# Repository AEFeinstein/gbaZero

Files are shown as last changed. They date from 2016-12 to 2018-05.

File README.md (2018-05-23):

View this project on [CADLAB.io](https://cadlab.io/project/1072). 

# gbaZero

One day I decided to buy a broken Gameboy Advance, gut it, and replace the innards with a Raspberry Pi powered board. This style of project has been attempted before in custom plastic (see [Game Grrl](https://learn.adafruit.com/game-grrl) and its derivitaves) and Nintendo plastic (see [Ryzee119's project](https://github.com/Ryzee119/GBA_Emulator-by-Ryzee119-) and [Game Pie Advance](http://gamepieadvance.com/)). Here's a little build log for my version of this project.

## Design

The design process was mostly me sitting at my desk doing research and CAD work in Inkscape and EAGLE.

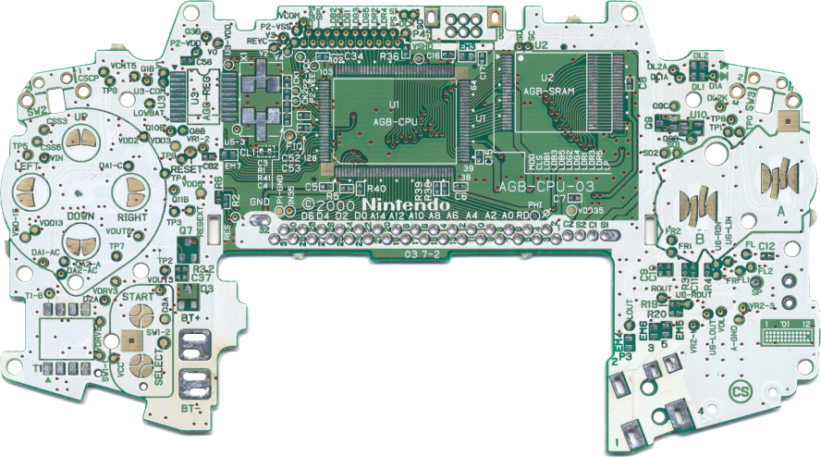
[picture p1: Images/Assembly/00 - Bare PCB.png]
00 - Bare PCB.png

To get the right PCB shape, I desoldered all the parts from a sacrificial PCB and took a 600dpi scan of it.

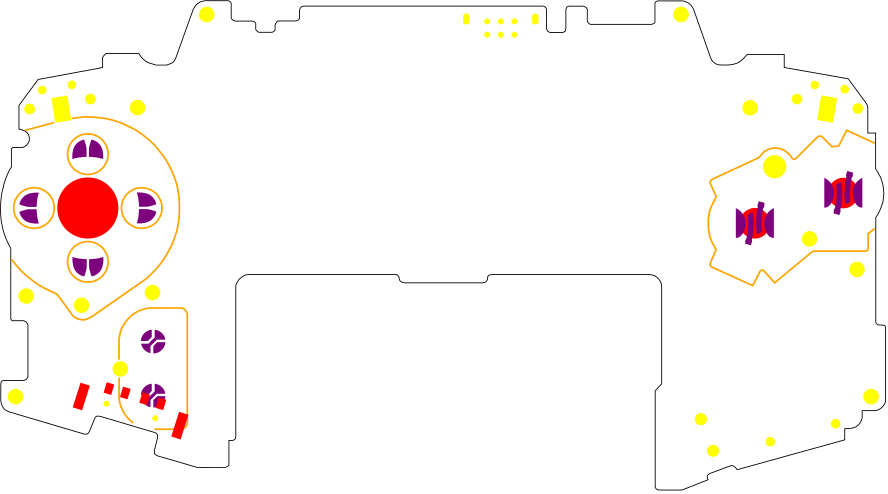
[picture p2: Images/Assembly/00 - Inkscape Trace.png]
00 - Inkscape Trace.png

That scan was then traced in Inkscape, and the resulting SVG was imported into EAGLE using [cmonr's svg2poly ULP](https://github.com/cmonr/Eagle-ULPs).

I wanted the wacky button footprints to be just like Nintendo's. I had a scan of the footprints open in an image viewer, overlaid an EAGLE window made transparent by [Peek Through](http://www.lukepaynesoftware.com/projects/peek-through/), and traced out the shape using the polygon tool. It's kind of like a high tech lightbox.

Ultimately I threw my work on the board shape and drilled holes out the window in favor of the shape from Ryzee119's project. I was almost guaranteed to mess something, and their's was already tested to be the right fit, so that seemed safer. I was also unaware of Ryzee119's project when I started all the scanning and tracing. I did keep the Nintendo-esque button footprints.

## Assembling the Hardware

### Power Circuitry

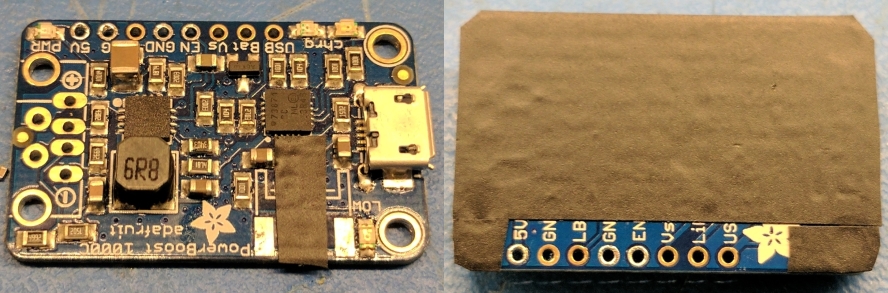
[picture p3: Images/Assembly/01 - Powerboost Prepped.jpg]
01 - Powerboost Prepped.jpg

It turns out using someone else's work is often easier than doing it yourself. In this case, I used a [PowerBoost 1000C](https://www.adafruit.com/products/2465) to manage charging the battery and supplying power for this board. It's a capable little board, so all I had to do was desolder the JST battery connector to trim the height and cover the backside with electrical tape because it will sit flush on the main board.

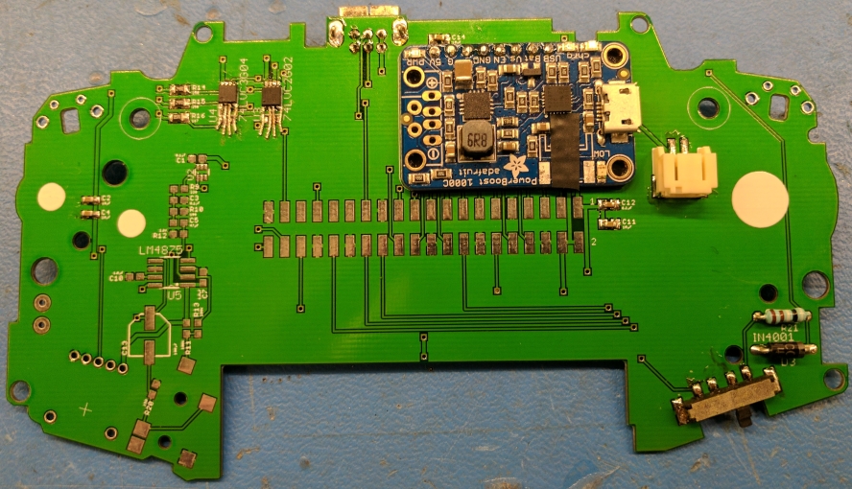
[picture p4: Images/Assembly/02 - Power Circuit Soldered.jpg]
02 - Power Circuit Soldered.jpg

Here's the power circuit all soldered up. I'm using a common anode tricolor LED and some NOR gates and inverters to display the GBA's state (powered on, charging, or low battery). The logic ICs are in the top left and the LED is on the other side of the board.

The switch in the bottom right was salvaged from a broken GBA. I couldn't find where to source a replacement for the life of me. The resistor and diode in the bottom right are a way to have the Raspberry Pi power off cleanly. Sure, one could just cut power to the Pi, but that puts the SD card at risk for corruption. The Enable pin on the PowerBoost is tied to both the switch and a GPIO (through a diode, so the GPIO doesn't get backpowered), so when the Pi boots it holds the PowerBoost on, even if the switch is turned off. Flicking the switch off does trigger a shutdown script, which shuts down cleanly and disables the PowerBoost at the end.

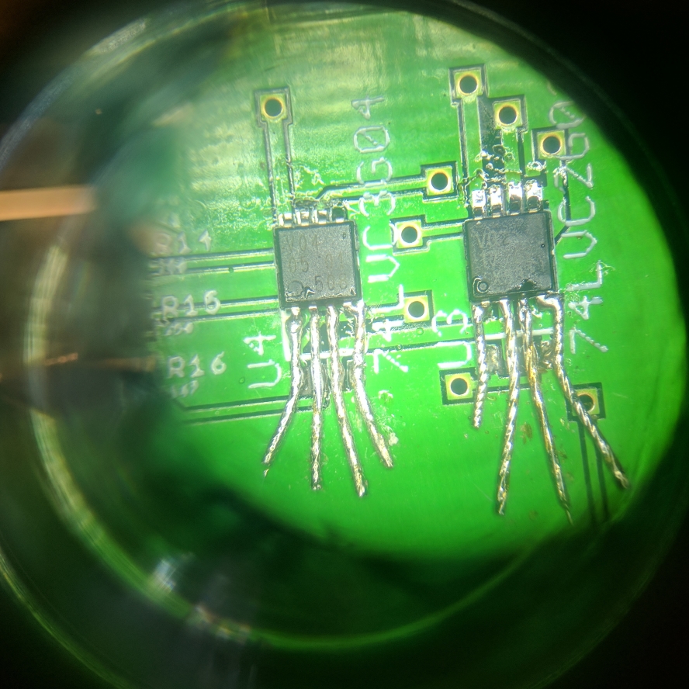
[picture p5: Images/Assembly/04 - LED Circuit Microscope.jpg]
04 - LED Circuit Microscope.jpg

Uhoh, notice those ugly wires coming off the logic ICs in the previous image? Turns out I either used the wrong footprint in EAGLE or ordered the wrong package part from Digi-Key. Either way, it needed some bridging. I realized I could take pictures with my phone through the stereo microscope in the lab, so I did. I trimmed the wires after this shot, and cleaned up the extra flux too.

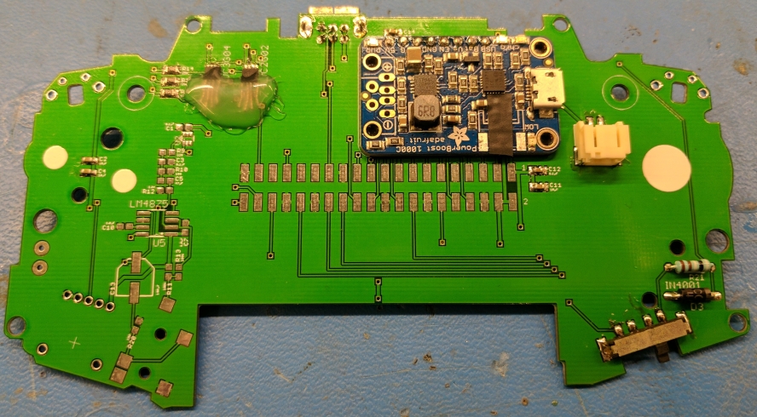
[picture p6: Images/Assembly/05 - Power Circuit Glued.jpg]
05 - Power Circuit Glued.jpg

There's nothing like a little hot glue to keep everything in place!

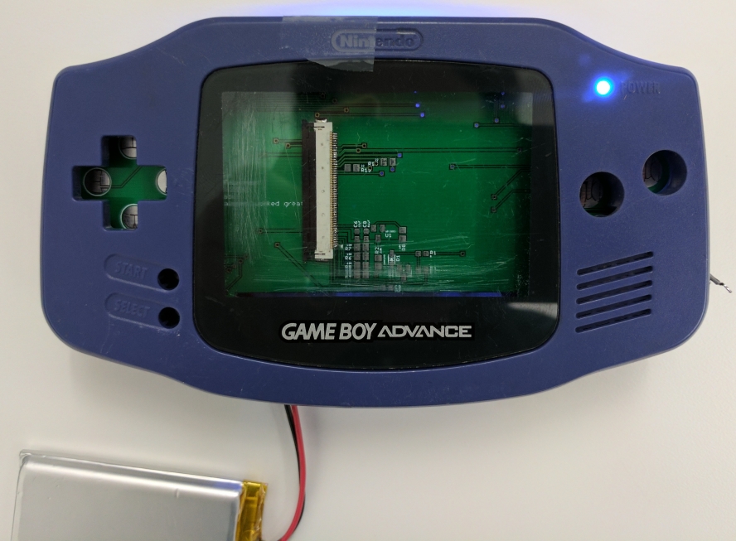
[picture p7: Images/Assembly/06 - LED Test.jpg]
06 - LED Test.jpg

Ta-da! The LED works and is in the right place for the light pipe. It may be a little too bright, but that's nothing a larger current limiting resistor can't fix. The LED is blue when the unit is powered on, green when it is charging, and red when the battery is low. The one wrinkle is that the LED is off when the unit is off, but charging. The original design assumed a common cathode LED instead of a common anode LED, which is what I ended up finding on Digi-Key. Rather than redo the logic, I just threw an inverter on at the end. Unfortunately the inverter was powered by the regulated voltage, so it doesn't invert unless the unit is on. Had the LED been common cathode, it would have been driven by the 5V USB charging voltage. Ah well.

Also of note, the board uses the original Link Cable connector and a custom cable for charging. The Raspberry Pi's RX and TX pins are also exposed on the Link Cable connector, so with an FTDI cable one can log into a terminal and fiddle around with the system. This ended up being way more convenient than SSHing into the system over wifi.

### Display Circuitry

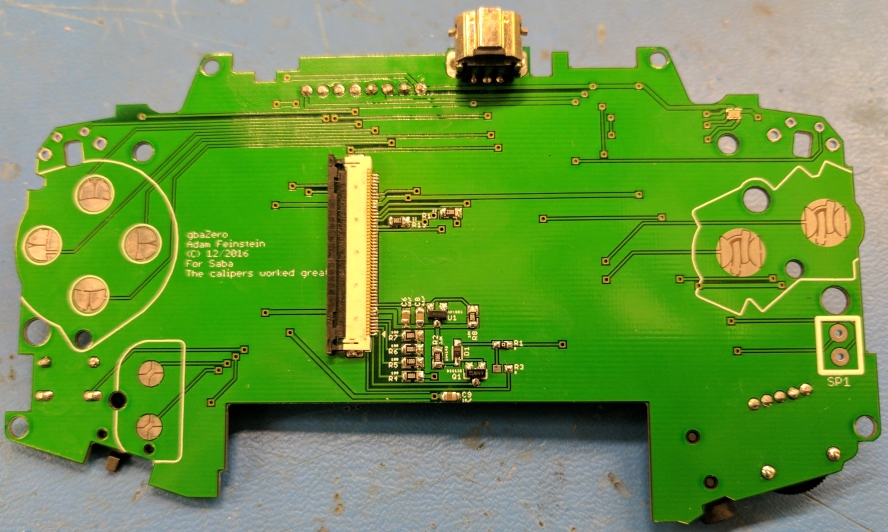
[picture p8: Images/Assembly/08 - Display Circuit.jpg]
08 - Display Circuit.jpg

Remember that part about using someone else's work? I'll call it standing on the shoulders of giants. Turns out Adafruit sells a [2.8" Raspberry Pi display](https://www.adafruit.com/products/2423) which fits pretty perfectly in a GBA. I took the [circuitry from their board](https://github.com/adafruit/Adafruit-PiTFT-Plus-2.8-PCB) and transposed it onto mine. Should work perfectly, right? Yeah, we'll get to that.

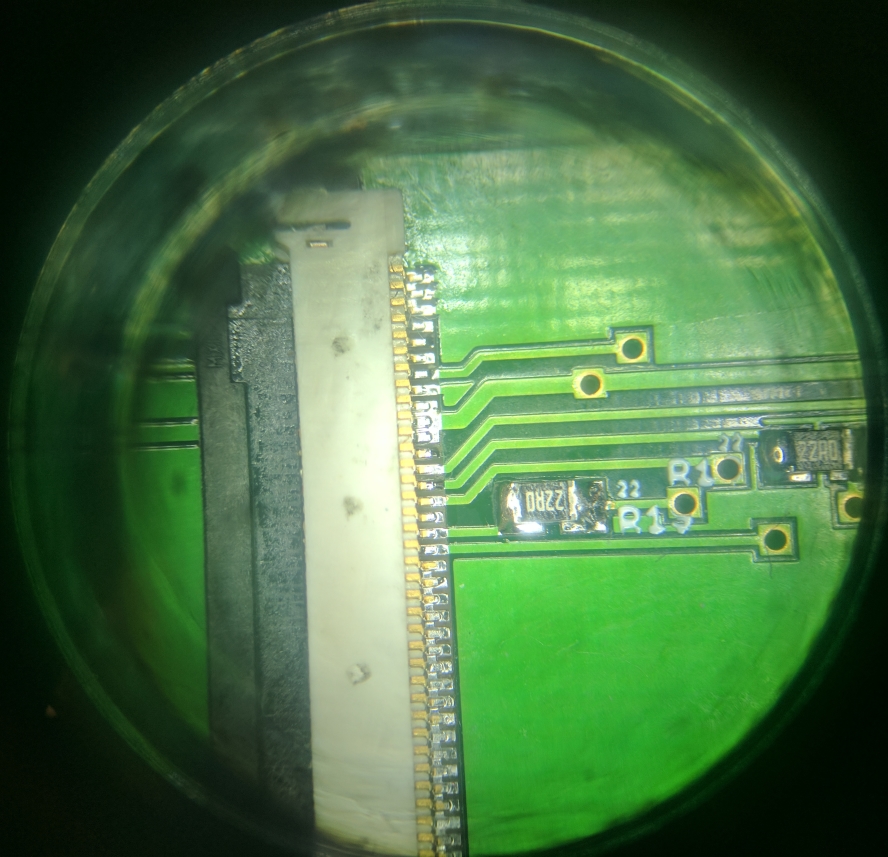
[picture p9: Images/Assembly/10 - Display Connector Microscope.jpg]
10 - Display Connector Microscope.jpg

Here's a gratuitious microscope shot. The display connector had 0.5mm pitch pins, which is the smallest thing I've soldered. Solder braid makes everything look super clean (and not bridged).

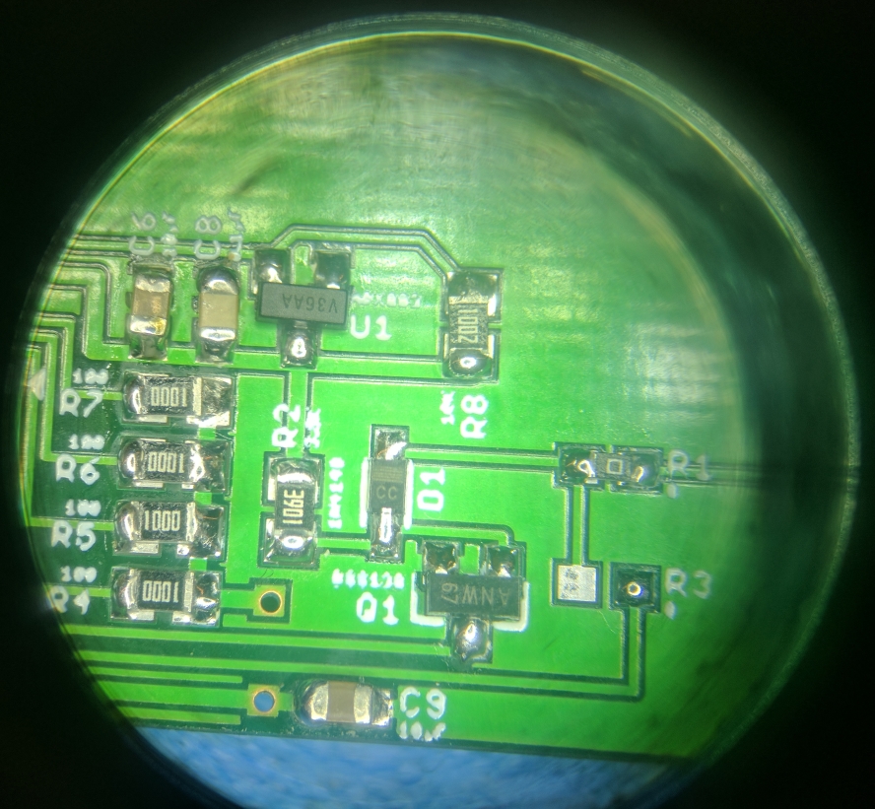
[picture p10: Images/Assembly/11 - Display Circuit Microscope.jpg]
11 - Display Circuit Microscope.jpg

Oh yeah, I was going wild with that microscope. There's actually a problem in this picture. I'll get to that shortly.

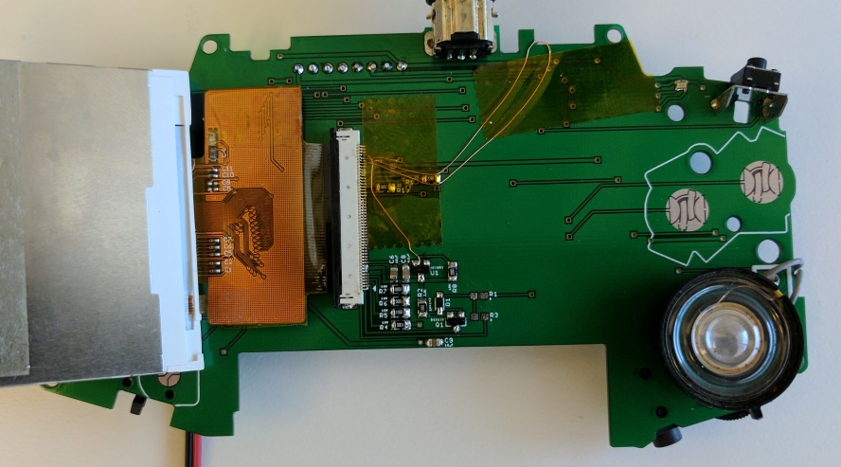
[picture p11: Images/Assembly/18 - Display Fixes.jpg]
18 - Display Fixes.jpg

Transposing a circuit only works if you do it correctly, which I did not. I crossed the I2C lines which send touchscreen data to the Raspberry Pi, so I had to cut those traces with a knife and reroute them with magnet wire. Those are the two wires going off the edge of the board. That didn't matter so much as I wasn't using the touchscreen anyway, but I like to be proper. The bigger issue is that I completely missed a trace that had been connected with a 0 ohm resistor on Adafruit's board. That was fixed with the third magnet wire running from the display connector to U1. I opted for kapton tape instead of hot glue to hold these fixes in place.

There was another issue with the display circuitry that prevented an image from being displayed, hinted at before. U1 is an APX803 voltage supervisor on a 3.3V line. However, I bought an APX803 which had a 4.63V threshold. D'oh. The Adafruit schematic didn't note the treshold level, and I must not have been paying much attention while filling my shopping cart. In lieu of ordering another supervisor, I stole the one from the Adafruit board and dropped it on mine.

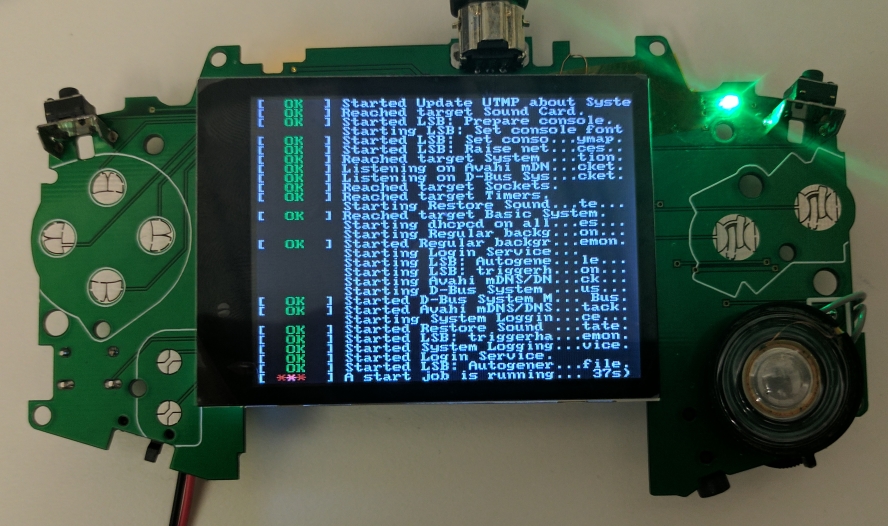
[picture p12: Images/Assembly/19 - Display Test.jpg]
19 - Display Test.jpg

Ta-da! With a few magnet wire fixes and a new supervisor, there's an image! This testing and debugging was done after all the parts were soldered, so these images aren't quite in chronological order. It would be hard to display anything without the Raspberry Pi.

### Audio Circuitry

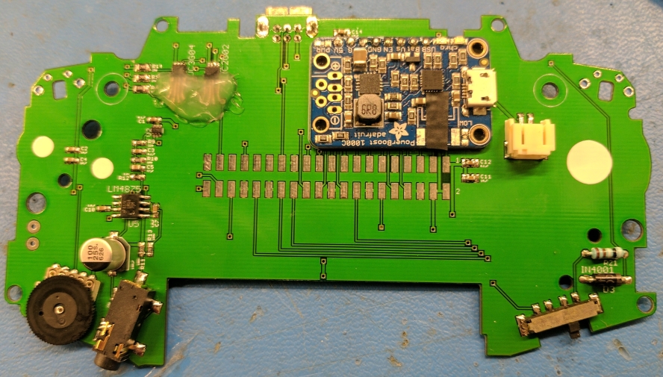
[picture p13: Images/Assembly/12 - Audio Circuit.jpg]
12 - Audio Circuit.jpg

While most Raspberry Pis have audio output, the Zero does not. It's the cost to pay for a tiny $5 board. Luckily, it can still output a PWM audio signal. A little RC filtering and amplifying later, and it should be good to go. The headphone jack and volume potentiometer were new parts. A minor annoyance, GND and 5V are swapped on the volume potentiometer, so rotating it towards max volume (according to the plastic shell) makes it quieter. 

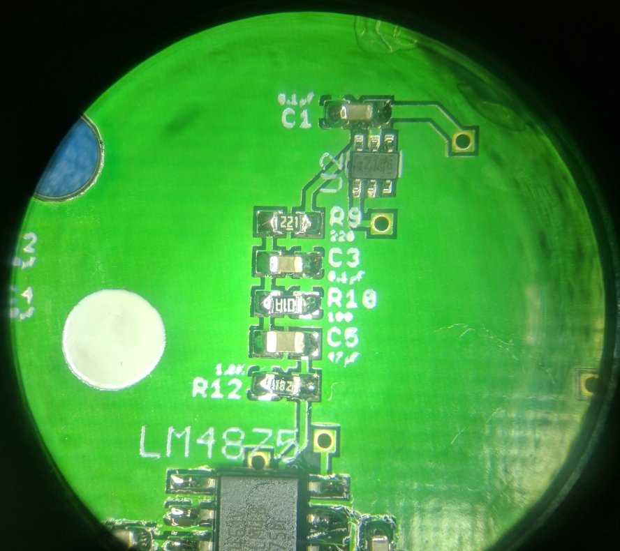
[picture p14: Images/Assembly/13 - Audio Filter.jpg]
13 - Audio Filter.jpg

Here's a microscope shot of the buffer and five passives that make up the filter. The design was taken from the Raspberry Pi 3 schematic. Once again, there's a problem in here. More on that shortly.

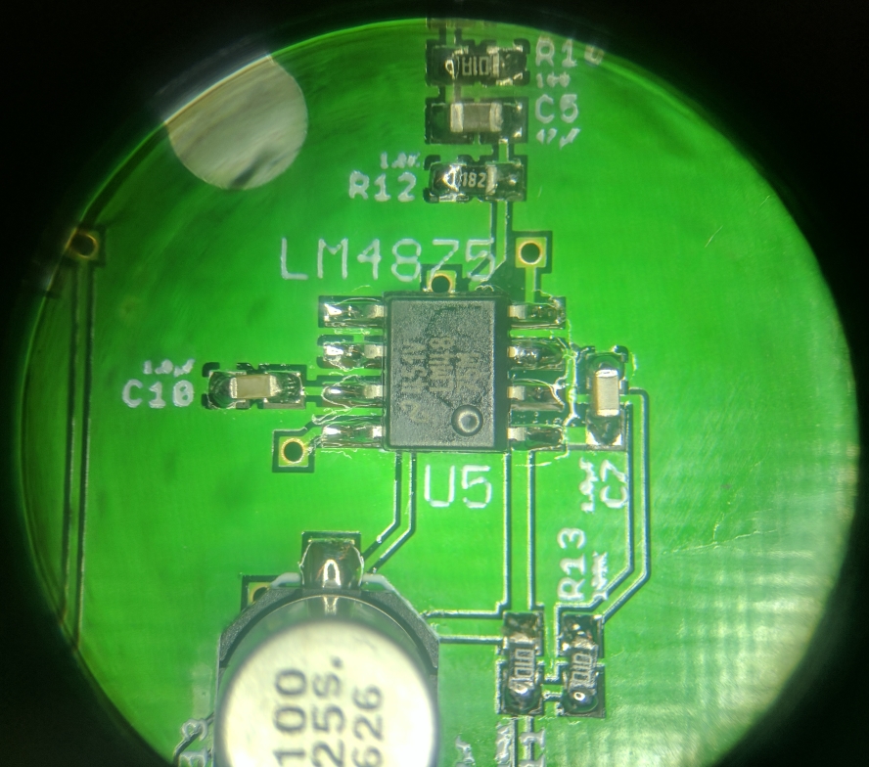
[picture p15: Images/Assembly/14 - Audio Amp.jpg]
14 - Audio Amp.jpg

The amplifier is an LM4875. That amp only does mono sound, but it can automatically switch between a speaker and a headphone jack. An earlier design had a separate analog switch IC which could handle stereo output, but was way more cumbersome. The GBA only has one speaker anyway (though headphones have two).

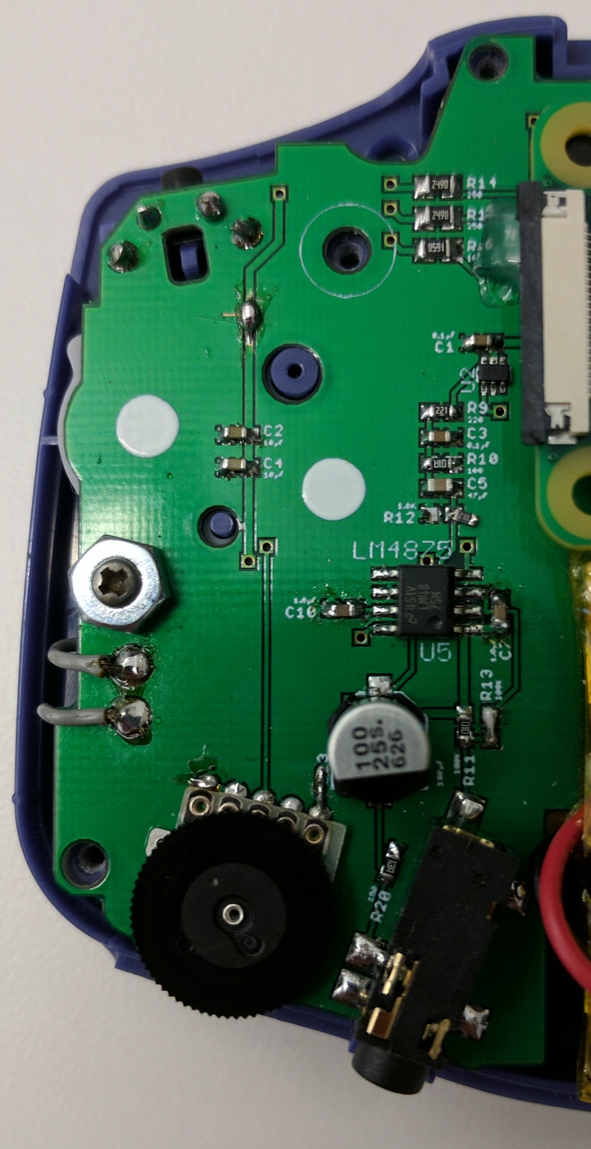
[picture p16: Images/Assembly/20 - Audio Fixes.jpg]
20 - Audio Fixes.jpg

So about that problem, when I went to test the audio, the speaker got hot. As a colleague said "you can't hear DC," and indeed there was an unexpected DC voltage across the speaker. The [Raspberry Pi 3 schematic](https://www.raspberrypi.org/documentation/hardware/raspberrypi/schematics/RPI-3B-V1_2-SCHEMATIC-REDUCED.pdf) I copied the audio circuitry from had a pulldown resistor right before the audio jack. This is great for headphones or speakers or what-have-you, but terrible for amplifier input. In fact, the [LM4875 datasheet](http://www.ti.com/lit/ds/symlink/lm4875.pdf) says to put a 0.22uF capacitor in line with the input signal to get rid of incoming DC voltage, which I did not do. All that had to change was to remove the last pulldown resistor before the amplifier and let the last capacitor filter out all the DC voltage. You can see R12 hanging off into nowhere, just so I wouldn't lose it.

This took me forever to figure out, and in fact the solution was proposed by a colleague who earned his name in the silkscreen for version two. Some failed debugging attempts were powering the audio circuitry with 3.3V instead of 5V (the cut and solder blob in the top left), replacing R13 with a wire, dis/reconnecting the volume potentiometer, and changing bypass capacitor values (C7 is two stacked capacitors in the picture above). Gross.

### Raspberry Pi Zero

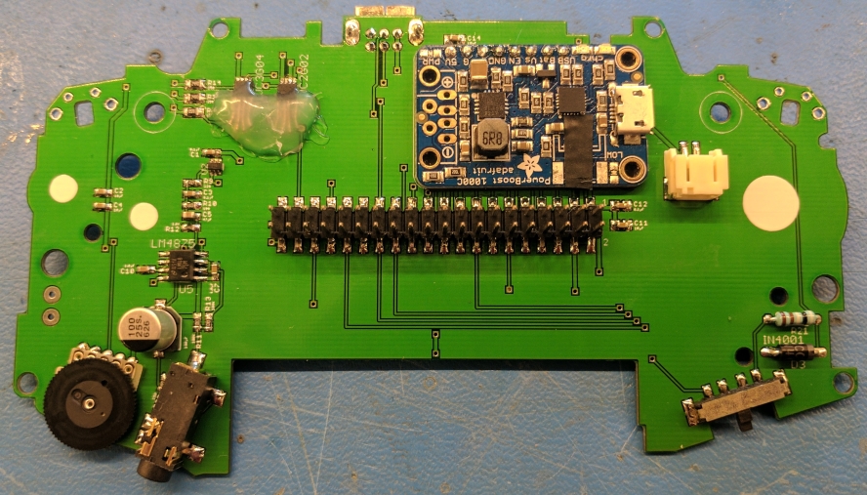
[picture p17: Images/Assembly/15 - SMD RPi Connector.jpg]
15 - SMD RPi Connector.jpg

Soldering on the Raspberry Pi proved to be the one part of this project that went as expected. First I soldered on a 40 pin SMD connector.

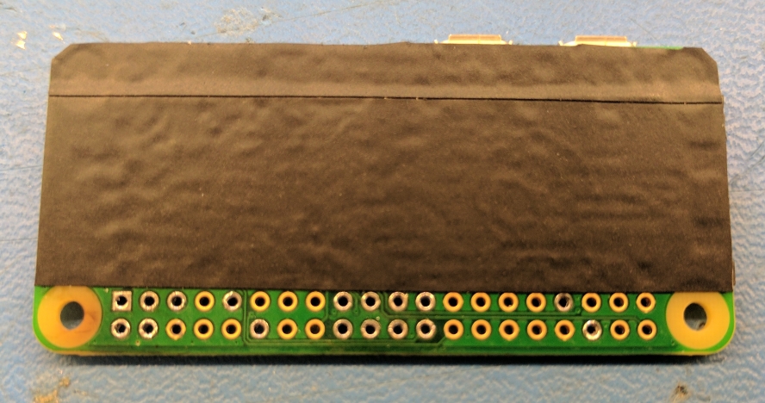
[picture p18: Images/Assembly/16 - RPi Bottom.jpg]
16 - RPi Bottom.jpg

Then I taped the bottom of the Raspberry Pi, since it would cantilever over the PowerBoost.

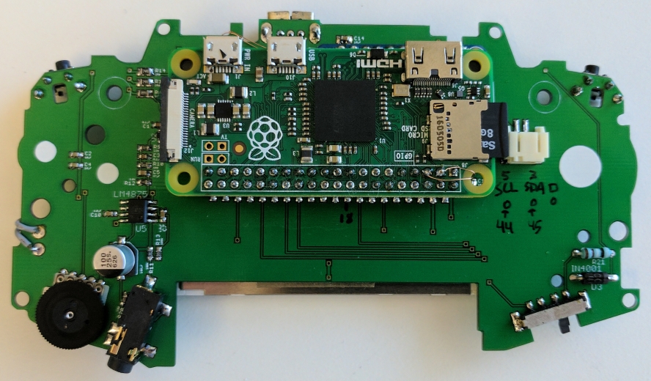
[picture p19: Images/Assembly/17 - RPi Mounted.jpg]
17 - RPi Mounted.jpg

Then I soldered it on the header. All good! This picture was taken after the display debugging, so you can see where those two magnet wires ended up. I also made a note to myself on the circuit board, seemed easier that way.

By now, the shoulder buttons had also been soldered on. I tried to use the original buttons to have a realistic feel. The buttons were tactile switch, but the plunger was made of a flexible rubber rather than a hard plastic. Unfortunately, one of the switches would not switch at all. I don't know what this poor Gameboy went through in a prior life, but it could not have been good. We had one 90 deggree tactile switch in the office, so I bent it's pins and jammed it on the board, which worked just fine. The shoulders currently have an asymetrical feel though, which kind of drives me nuts.

### It Lives!

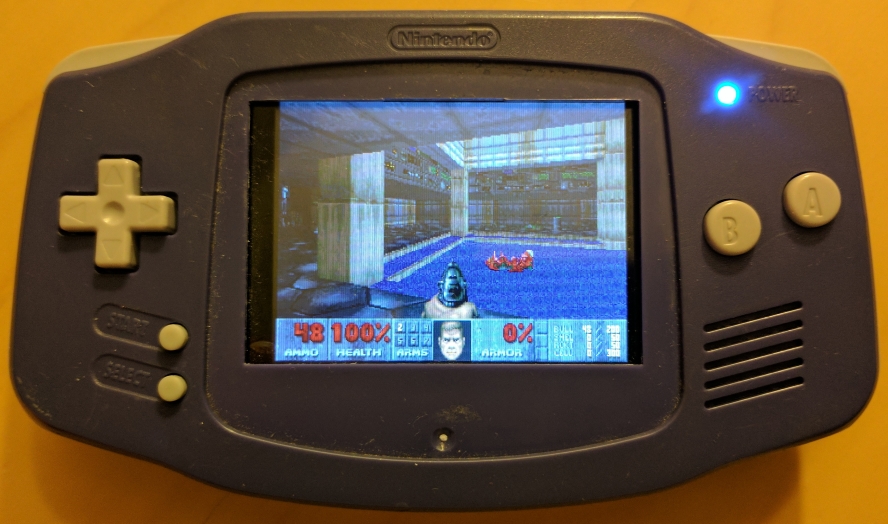
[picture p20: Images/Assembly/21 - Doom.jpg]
21 - Doom.jpg

At the end, everything get put in the salvaged plastic, and yes, it runs Doom! I popped off the old display lens because it was so roughed up and the Adafruit display can hold it's own.

### The Plastic

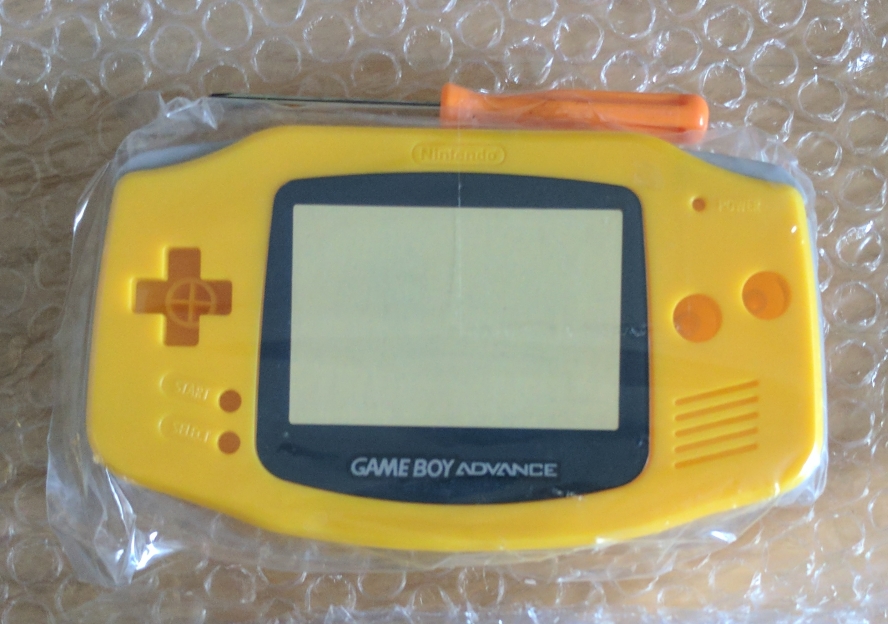
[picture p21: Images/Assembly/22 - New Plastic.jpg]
22 - New Plastic.jpg

There are tons of Gameboy Advance shell replacement kits available on Amazon, so it seemed right to replace the scarred purple shell. I went with yellow because my first Gameboy, a Color, was yellow. Thanks Mom & Dad!

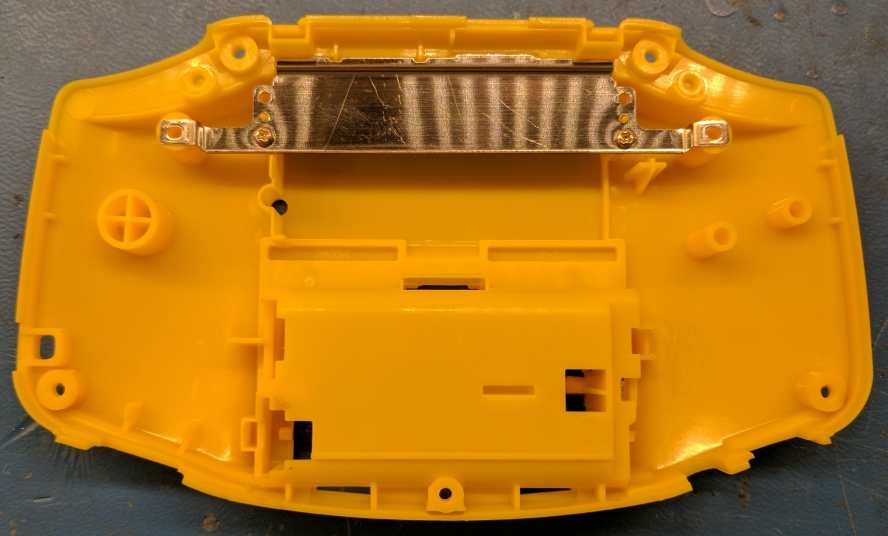
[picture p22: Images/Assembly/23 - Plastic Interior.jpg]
23 - Plastic Interior.jpg

The plastic has all sorts of interior supports for the cartridge and battery, but those need to be removed here.

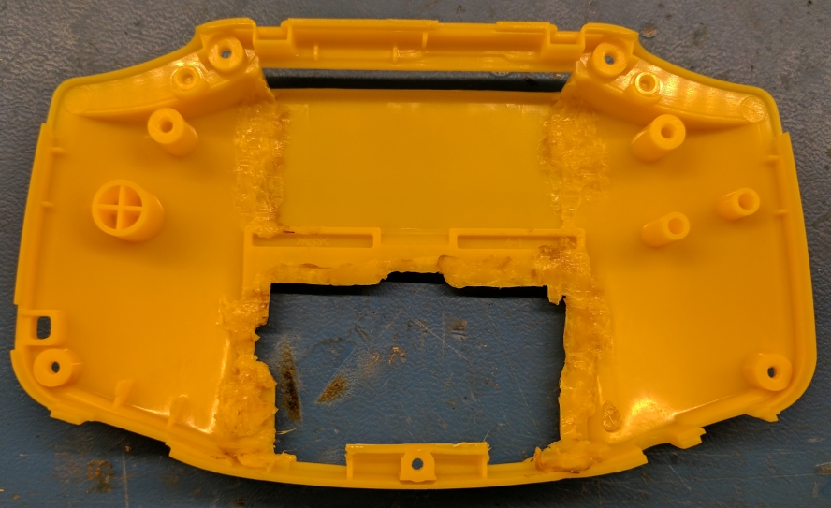
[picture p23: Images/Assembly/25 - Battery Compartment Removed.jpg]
25 - Battery Compartment Removed.jpg

A dremel probably would have worked wonders here, but I opted to "cut" the plastic away with a soldering iron. Melted ABS fumes aren't pleasant (or healthy), so this work was done under a vacuum.

The battery compartment was a little trickier to remove partially because it was larger and partially because I had to remove material close to that bottom edge. I ended up applying a little too much heat and the bottom edge warped a bit. It's not bad enough to prevent the shell from fitting, but you can see it from the outside if you're looking for it. Plus I know it's there. Dang.

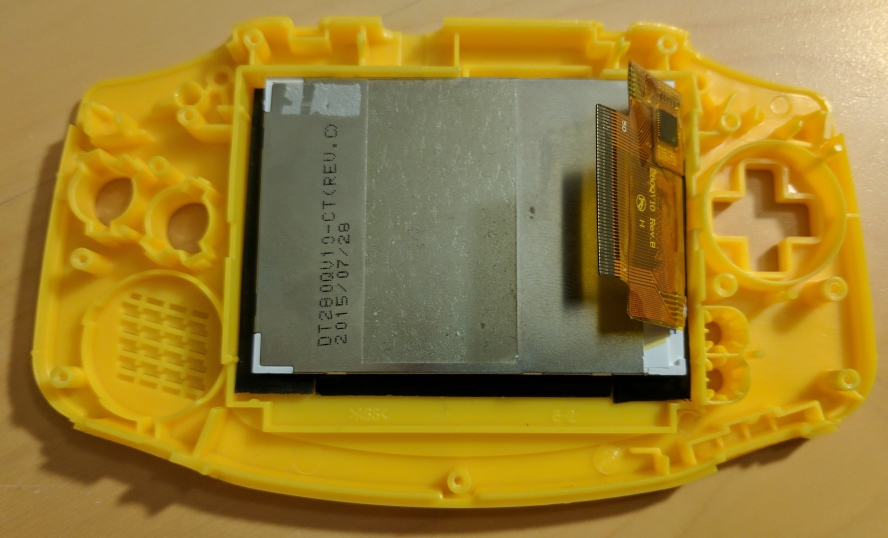
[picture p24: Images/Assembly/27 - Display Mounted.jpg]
27 - Display Mounted.jpg

The display is held in place with the thinnest double sided foam tape I could find on Digi-Key. I finally removed the film protecting the screen before mounting, and boy does it look clearer. It's not easy to finagle the ribbon cable into the connector when the display is mounted, but it's doable.

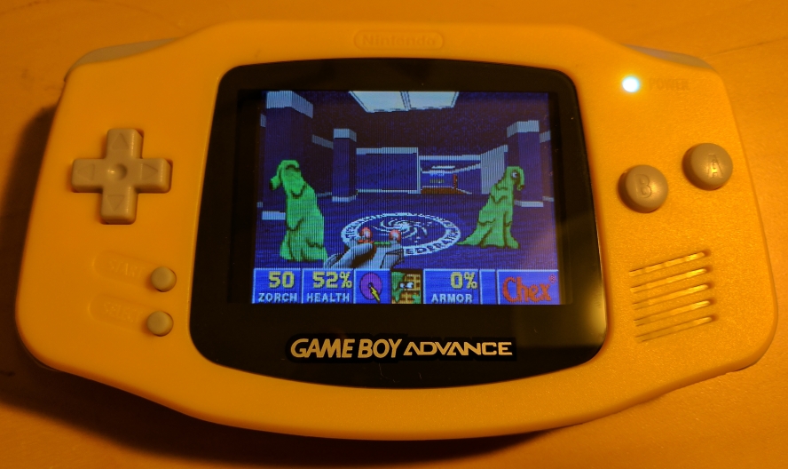
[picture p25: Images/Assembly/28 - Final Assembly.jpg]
28 - Final Assembly.jpg

And voila! The display lens has been installed and I'm done. What better way to celebrate than with the greatest first person shooter of all time, Chex Quest?

### PCB v2

I wasn't really happy with the IC pad size for the power LED logic, or the asymmetrical shoulder buttons, or the fix wires for the display, and I wanted to try out Seeed Studio's PCB Assembly service, so I recruited a few friends to defray the cost for a batch of 10 PCBs fixed the layout, and had them built. Seeed Studio couldn't assemble the whole board, but it was quite nice not having to solder everything. Here it is in all its glory.

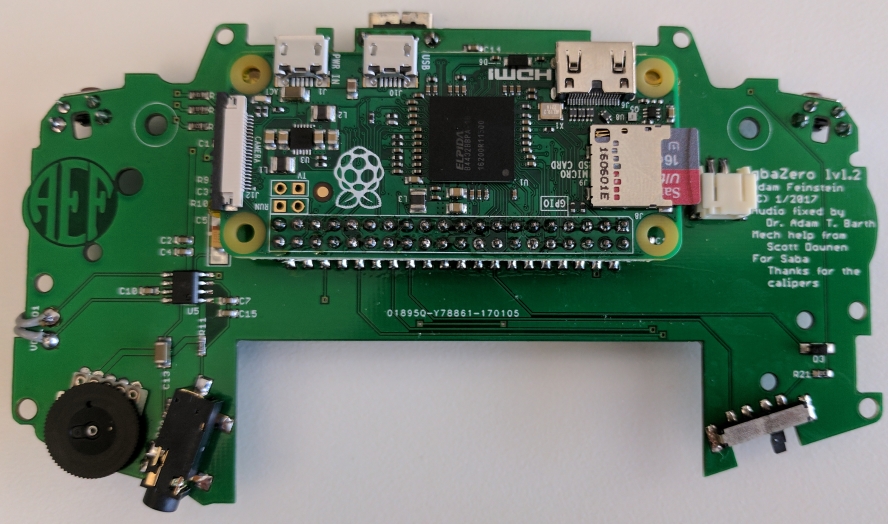
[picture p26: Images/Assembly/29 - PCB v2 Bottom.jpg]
29 - PCB v2 Bottom.jpg

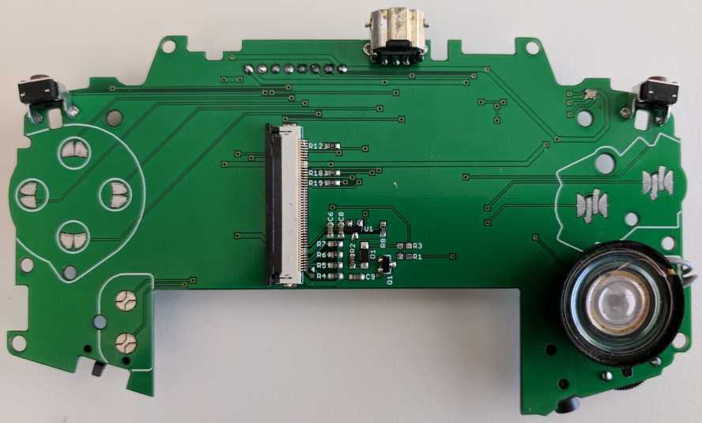
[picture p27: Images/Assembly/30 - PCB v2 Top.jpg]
30 - PCB v2 Top.jpg


But of course there was something still broken (hardware is hard). Even though the power LED's logic gates are still powered when the unit is off but charging, the LED itself is not. Nothing a wire couldn't fix. This one I'll have to live with.
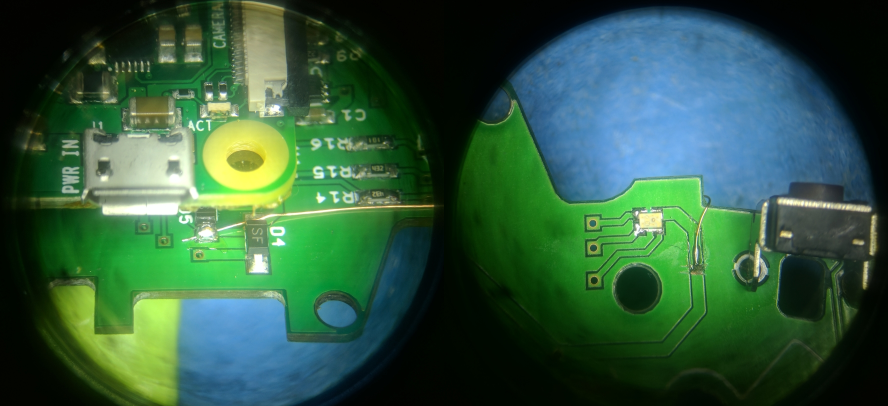
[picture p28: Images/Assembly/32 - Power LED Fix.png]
32 - Power LED Fix.png


I noticed some odd behaviour when trying to turn on and off the gbaZero v2 PCB as well. After a little investigation, it turns out that the original GBA power "switch" was actually a linear potentiometer. Seriously Nintendo? It kind of works as a switch, but not always, which is why I hadn't noticed until now. I'm not planning on a v3, so I scoured Digi-Key for a switch with the same footprint and [managed to find one](https://www.digikey.com/product-detail/en/nidec-copal-electronics/CSS-1310TB/563-1095-1-ND/1124228). The actuator dimensions were slightly off, so I had to 3D print a new piece. Works like a charm!
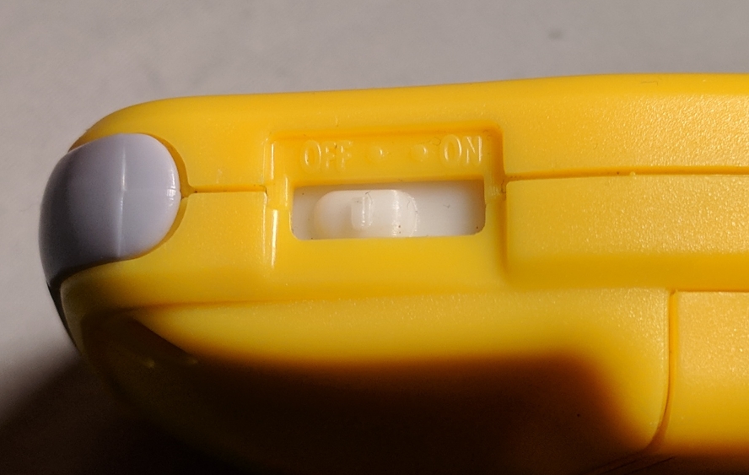
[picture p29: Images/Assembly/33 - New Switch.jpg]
33 - New Switch.jpg


At the very end of the project, the Wind Fish is saved! I found that deeply satisfying.
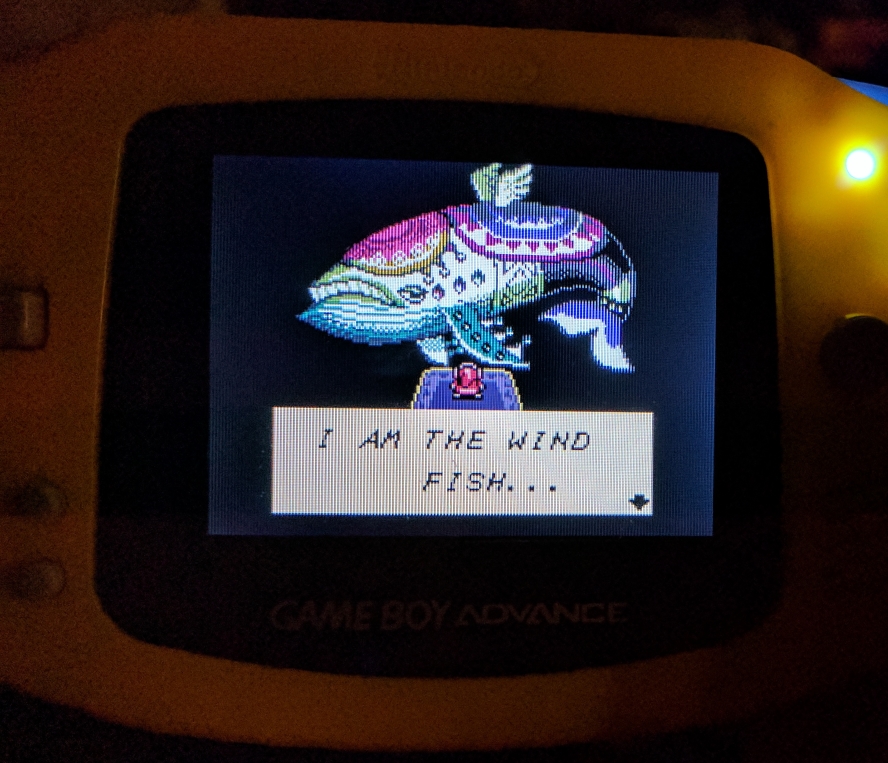
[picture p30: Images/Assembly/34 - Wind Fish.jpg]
34 - Wind Fish.jpg


## The Software

Software doesn't get pretty pictures, sorry.

I connected a USB wifi dongle to the Raspberry Pi using a USB OTG cable and configured with [these instructions](http://weworkweplay.com/play/automatically-connect-a-raspberry-pi-to-a-wifi-network/). I only used wifi during configuration.

The base OS is [Adafruit's version of Jessie Lite](https://learn.adafruit.com/adafruit-2-8-pitft-capacitive-touch/easy-install), with kernel drivers for the display already built in. [RetroPie](https://retropie.org.uk/) was installed on top of that, which handles all of the game playing. I also used [another of Adafruit's guides](https://learn.adafruit.com/running-opengl-based-games-and-emulators-on-adafruit-pitft-displays/pitft-setup) to install fbcp, necessary to draw to the display from RetroPie. 

[Retrogame](https://github.com/adafruit/Adafruit-Retrogame) was used to map the button GPIOs to actual key input. I had to further modify the mappings in Emulationstation (a part of RetroPie) because some games expected key combinations that happened to do other things, like quit the game.

[Wiring Pi](http://wiringpi.com/) was used to set and monitor the power switch GPIOs.

[These instructions](http://stackoverflow.com/questions/33753985/raspberry-pi-auto-login-without-etc-inittab/34755133#34755133) enabled auto-login, and [these instructions](https://www.raspberrypi.org/forums/viewtopic.php?f=78&t=58233) started Emulationstation automatically.

One hiccup was that initially there was no audio output, even though it was set to play over the "3.5mm jack" instead of HDMI. The solution? Unmute the audio. Occam's Razor hard at work.

The other hiccup was a hardware failure. Every once in a while, though with increasing frequency, the Raspberry Pi wouldn't boot, but would print "mmc0: fsm 1, hsts 1" to the terminal in an infinite loop. Turns out the SD card was busted and had to be replaced. Good thing I made a system image after tweaking the install to my liking.

## Final Thoughts
Hardware design is hard, and not everything can be fixed in software. Most of the janky fixes from the v1 PCB were fixed in the v2 one, but it's still not perfect. If only fabricating a board was as easy as typing "make." Also, Link's Awakening DX is still awesome.

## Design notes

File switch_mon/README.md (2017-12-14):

switch_mon is a small C program which polls the pin connected to power switch.
If the switch is switched off for four seconds, the system will kill any emulators.
If the switch is then switched on for four seconds, it will disconnect the internal enable for the PowerBoost 1000c and safely shutdown.
If the switch is then switched off, the system will power down.

switch_mon.service is a systemd service to run switch_mon in the background
switch_mon_setup.sh will install the service

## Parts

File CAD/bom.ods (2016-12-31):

SEEED MPN | Qty | Value | Device | Package | Parts | Description | Part Number | URL
302010138 | 5 | 0.1µF | CAP_CERAMIC0603 | 603 | C1, C3, C7, C8, C12 | Ceramic Capacitors | 311-1088-1-ND | https://www.digikey.com/product-detail/en/yageo/CC0603KRX7R7BB104/311-1088-1-ND/302998
302010183 | 1 | 100µF | CAP_CERAMIC1206 | 1206 | C13 | Ceramic Capacitors | 490-4539-1-ND | http://www.digikey.com/product-detail/en/murata-electronics-north-america/GRM31CR60J107ME39L/490-4539-1-ND/1033313
302010103 | 8 | 10µF | CAP_CERAMIC0603 | 603 | C2, C4, C6, C9, C10, C11, C14, C15 | Ceramic Capacitors | 490-3298-1-ND | http://www.digikey.com/product-detail/en/murata-electronics-north-america/GRM188R60G106ME47D/490-3298-1-ND/702839
302020005 | 1 | 47µF | CAP_TANTALUMC/6032_REFLOW | EIA6032-28/C-R | C5 | Tantalum Capacitors | 478-8903-1-ND | http://www.digikey.com/product-detail/en/avx-corporation/TAJC476K006RNJ/478-8903-1-ND/4561769
304020012 | 4 | B0540WQ-7-F | DIODESOD-123 | SOD-123 | D1, D3, D4, D5 | Diode | B0540WQ-7-FDICT-ND | http://www.digikey.com/product-detail/en/diodes-incorporated/B0540WQ-7-F/B0540WQ-7-FDICT-ND/6193618 | B0540W
 | 1 | LTST-C19HE1WT | LTST-C19HE1WT | WL-SBCW-0606 | D2 |  | 160-2162-1-ND | https://www.digikey.com/product-detail/en/lite-on-inc/LTST-C19HE1WT/160-2162-1-ND/4866310
 | 1 | SWTCHCRFT_3.5JACK5-JACK-SMD | SWTCHCRFT_3.5JACK5-JACK-SMD | 4-JACK-SMD | J1 | Switchcraft 3.5mm Stereo Audio Jack |  | https://www.digikey.com/product-detail/en/switchcraft-inc/35RASMT4BHNTRX/SC1488-1-ND/2754493
 | 1 | 50_PIN_CON | DISP_LCD_CTP28 | FPC-50-CON | P1 | 2.83" 240x320 Pixel Capacitive Touch Display | WM6785CT-ND | https://www.digikey.com/product-detail/en/molex-llc/0541325062/WM6785CT-ND/3044199
 | 1 | TFT Display |  |  | P1 (2) | 2.83" 240x320 Pixel Capacitive Touch Display | 1983 | https://www.adafruit.com/products/1983
 | 1 |  | JST_2PIN | JSTPH2 | P2 | JST 2-Pin Right-Angle Connector | 455-1749-1-ND | https://www.digikey.com/product-detail/en/jst-sales-america-inc/S2B-PH-SM4-TB(LF)(SN)/455-1749-1-ND/926846
 | 1 | LINK_CONNECTOR | LINK_CONNECTOR | LINK_CONNECTOR | P3 |  |  | FROM GBA
 | 1 | BSS138 | MOSFET-NWIDE | SOT23-WIDE | Q1 | N-Channel Mosfet | 568-10308-1-ND | http://www.digikey.com/product-detail/en/nxp-usa-inc/BSS138P,215/568-10308-1-ND/4162471
301010292 | 3 | 0 | RESISTOR0603 | 603 | R1, R3, R12 | Resistors | 311-0.0GRCT-ND | https://www.digikey.com/product-detail/en/yageo/RC0603JR-070RL/311-0.0GRCT-ND/729622
301010196 | 1 | 100K | RESISTOR0603 | 603 | R11 | Resistors | 311-100KHRCT-ND | https://www.digikey.com/product-detail/en/yageo/RC0603FR-07100KL/311-100KHRCT-ND/729836
301010300 | 2 | 250 | RESISTOR0603 | 603 | R14, R15 | Resistors | 311-249HRCT-ND | https://www.digikey.com/product-detail/en/yageo/RC0603FR-07249RL/311-249HRCT-ND/730032
301010163 | 1 | 167 | RESISTOR0603 | 603 | R16 | Resistors | 311-169HRCT-ND | https://www.digikey.com/product-detail/en/yageo/RC0603FR-07169RL/311-169HRCT-ND/729925
 | 1 | 10K | RK10J12E0A0A | RK10J12E0A0A | R17 |  | 688-RK10J12E0A0A | https://www.mouser.com/Search/ProductDetail.aspx?qs=nR5Mw3RKkX43NuPtXzIvHQ%3d%3d
301010289 | 2 | 22 | RESISTOR0603 | 603 | R18, R19 | Resistors | 311-22.0HRCT-ND | https://www.digikey.com/product-detail/en/yageo/RC0603FR-0722RL/311-22.0HRCT-ND/730002
301010101 | 1 | 3.9K | RESISTOR0603 | 603 | R2 | Resistors | 311-3.90KHRCT-ND | https://www.digikey.com/product-detail/en/yageo/RC0603FR-073K9L/311-3.90KHRCT-ND/730083
301010090 | 1 | 150 | RESISTOR0603 | 603 | R20 | Resistors | 311-150HRCT-ND | https://www.digikey.com/product-detail/en/yageo/RC0603FR-07150RL/311-150HRCT-ND/729905
301010090 | 5 | 100 | RESISTOR0603 | 603 | R4, R5, R6, R7, R10 | Resistors | 311-100HRCT-ND | https://www.digikey.com/product-detail/en/yageo/RC0603FR-07100RL/311-100HRCT-ND/729835
301010299 | 2 | 10K | RESISTOR0603 | 603 | R8, R21 | Resistors | 311-10.0KHRCT-ND | https://www.digikey.com/product-detail/en/yageo/RC0603FR-0710KL/311-10.0KHRCT-ND/729827
301010163 | 1 | 220 | RESISTOR0603 | 603 | R9 | Resistors | 311-220HRCT-ND | https://www.digikey.com/product-detail/en/yageo/RC0603FR-07220RL/311-220HRCT-ND/730008
 | 1 | D-PAD | D-PAD | D-PAD | S1 |  |  | FROM GBA
 | 2 | SHOULDER_BUTTON | SHOULDER_BUTTON | SHOULDER_BUTTON | S2, S3 |  | EG2507-ND | https://www.digikey.com/product-detail/en/e-switch/tl1105vf100q/eg2507-nd/378973
 | 1 | START_SELECT_BUTTON | START_SELECT_BUTTON | START_SELECT_BUTTON | S4 |  |  | FROM GBA
 | 1 | AB_BUTTON | AB_BUTTON | AB_BUTTON | S5 |  |  | FROM GBA
 | 1 | PWR_SWITCH | PWR_SWITCH | PWR-SWITCH | S6 |  |  | FROM GBA
 | 1 | SPEAKER | SPEAKER | SPEAKER | SP1 |  |  | FROM GBA
 | 1 | APX803 | AXP083-SAG | SOT23 | U1 |  | APX803-31SAG-7DICT-ND | https://www.digikey.com/product-detail/en/diodes-incorporated/APX803-31SAG-7/APX803-31SAG-7DICT-ND/2285950
 | 1 | NC7WZ16 | NC7WZ16 | SC-70-6 | U2 |  | NC7WZ16P6XCT-ND | https://www.digikey.com/product-detail/en/fairchild-semiconductor/NC7WZ16P6X/NC7WZ16P6XCT-ND/673403
 | 1 | 74LVC2G02 | 74LVC2G02 | TSSOP-8 | U3 |  | 568-7673-1-ND | https://www.digikey.com/product-detail/en/nxp-usa-inc/74LVC2G02DP,125/568-7673-1-ND/2753817
 | 1 | 74LVC3G04 | 74LVC3G04 | TSSOP-8 | U4 |  | 568-8985-1-ND | https://www.digikey.com/product-detail/en/nxp-usa-inc/74LVC3G04DP,125/568-8985-1-ND/2813903
 | 1 | LM4875 | LM4875 | SO-8 | U5 | LM4875 | 296-35282-1-ND | https://www.digikey.com/product-detail/en/texas-instruments/LM4875MX-NOPB/296-35282-1-ND/3738990
 | 1 | RPI-ZEROSMD | RPI-ZEROSMD | RPI-SMD | U6 |  | 609-3124-ND | https://www.digikey.com/product-detail/en/amphenol-fci/95157-440LF/609-3124-ND/1824561
 | 1 | RPI-ZEROSMD | RPI-ZEROSMD | RPI-SMD | U6 (2) |  | 2885 | https://www.adafruit.com/products/2885
 | 1 | POWERBOOST-1000C | POWERBOOST-1000C | POWERBOOST-1000C | U7 |  | 2465 | https://www.adafruit.com/products/2465
 | 1 | 2000mAh Battery | 2000mAh Battery | 2000mAh Battery | U7 (2) |  | 2011 | https://www.adafruit.com/products/2011
 | 1 | GBA for Parts, Salvaging |  |  |  |  |  | www.ebay.com
 | 1 | GBA Plastic |  |  |  |  |  | www.amazon.com
 | 1 | Link Cable |  |  |  |  |  | www.amazon.com
 | 1 | MicroSD card (>=16GB) |  |  |  |  |  | www.amazon.com
 | 1 | PCB |  |  |  |  |  | www.seeedstudio.com

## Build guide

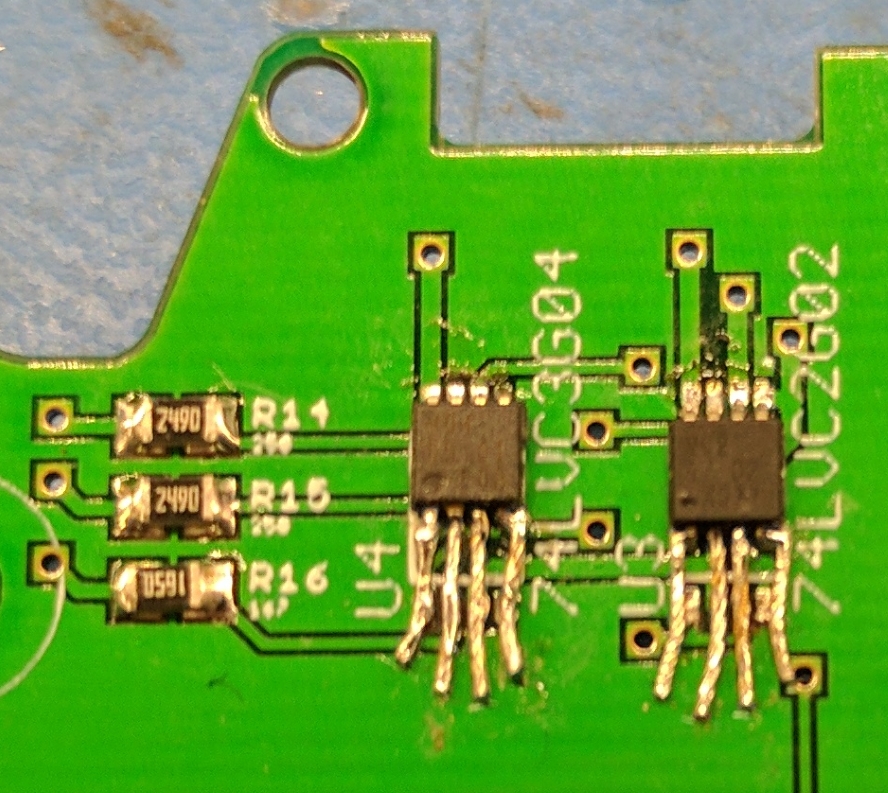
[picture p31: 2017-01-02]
Images/Assembly/03 - LED Circuit.jpg

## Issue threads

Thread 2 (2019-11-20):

Add 2 more buttons

ggdaltoso, 2019-11-20:
Hi, @AEFeinstein ! What amazing project do you have here!

I would like to build something like yours but with 2 more buttons on the right side (A, B, X, Y).

I already have most of the pieces listed such as PowerBoost 1000C, the GBA Case (with those 2 more buttons) and for the others, like audio, display, etc, it would not be too difficult to get the pieces.

Since I do not have the knowledge to modify your project, I was thinking if you could not help me.

AEFeinstein, 2019-11-20:
Hi @ggdaltoso. I'm not currently working on this project, nor do I plan to work on it.

If you want to modify it to add more buttons, you'll have to add them to the EAGLE schematic on some GPIO first (https://github.com/AEFeinstein/gbaZero/blob/master/CAD/gba-zero.sch), lay them out on the board (https://github.com/AEFeinstein/gbaZero/blob/master/CAD/gba-zero.brd), and modify the software to map those buttons (https://github.com/AEFeinstein/gbaZero#the-software).

That's all I can recommend. Good luck.

ggdaltoso, 2019-11-20:
Thanks, @AEFeinstein

I'll try to follow your guide. I forked your repo and, if you want, I could open a pull request with my modifications.

AEFeinstein, 2019-11-20:
I don't have EAGLE installed anymore since it requires an Autocad account (I've since moved to KiCAD), so I wouldn't be able to verify your changes. I'd also like to keep this project with just two buttons, so it does not need to drill any more holes in the plastic. You can make whatever changes you want, but I won't accept a pull request.

Closed 2024-06-03.

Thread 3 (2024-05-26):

a question about designing my own board for a gbazero

steventylerseanherr, 2024-05-26:
hi
i plan to follow in your footsteps and build a pi zero powered gba myself just with support for aftermarket gba mods
and i was wondering if you thought it might be possible to make a new board that supports all / most of the after market gba parts
mostly things like the funnyplaying usb-c power pak and the funnyplaying ita screen and shells

just wondering before i go digging into learning hardware design and stuff lol

AEFeinstein, 2024-05-26:
If you're asking if it's possible for me to do it, nah, I don't have the time. If you're asking if it's possible in general, probably?

You could take the basic board shape here and modify it to be more electrically like a GBA. You'd have to more closely mimic things like the screen connector and driver, battery connectors, and anything else you'd want to be compatible with mods.

Closed 2024-05-26.

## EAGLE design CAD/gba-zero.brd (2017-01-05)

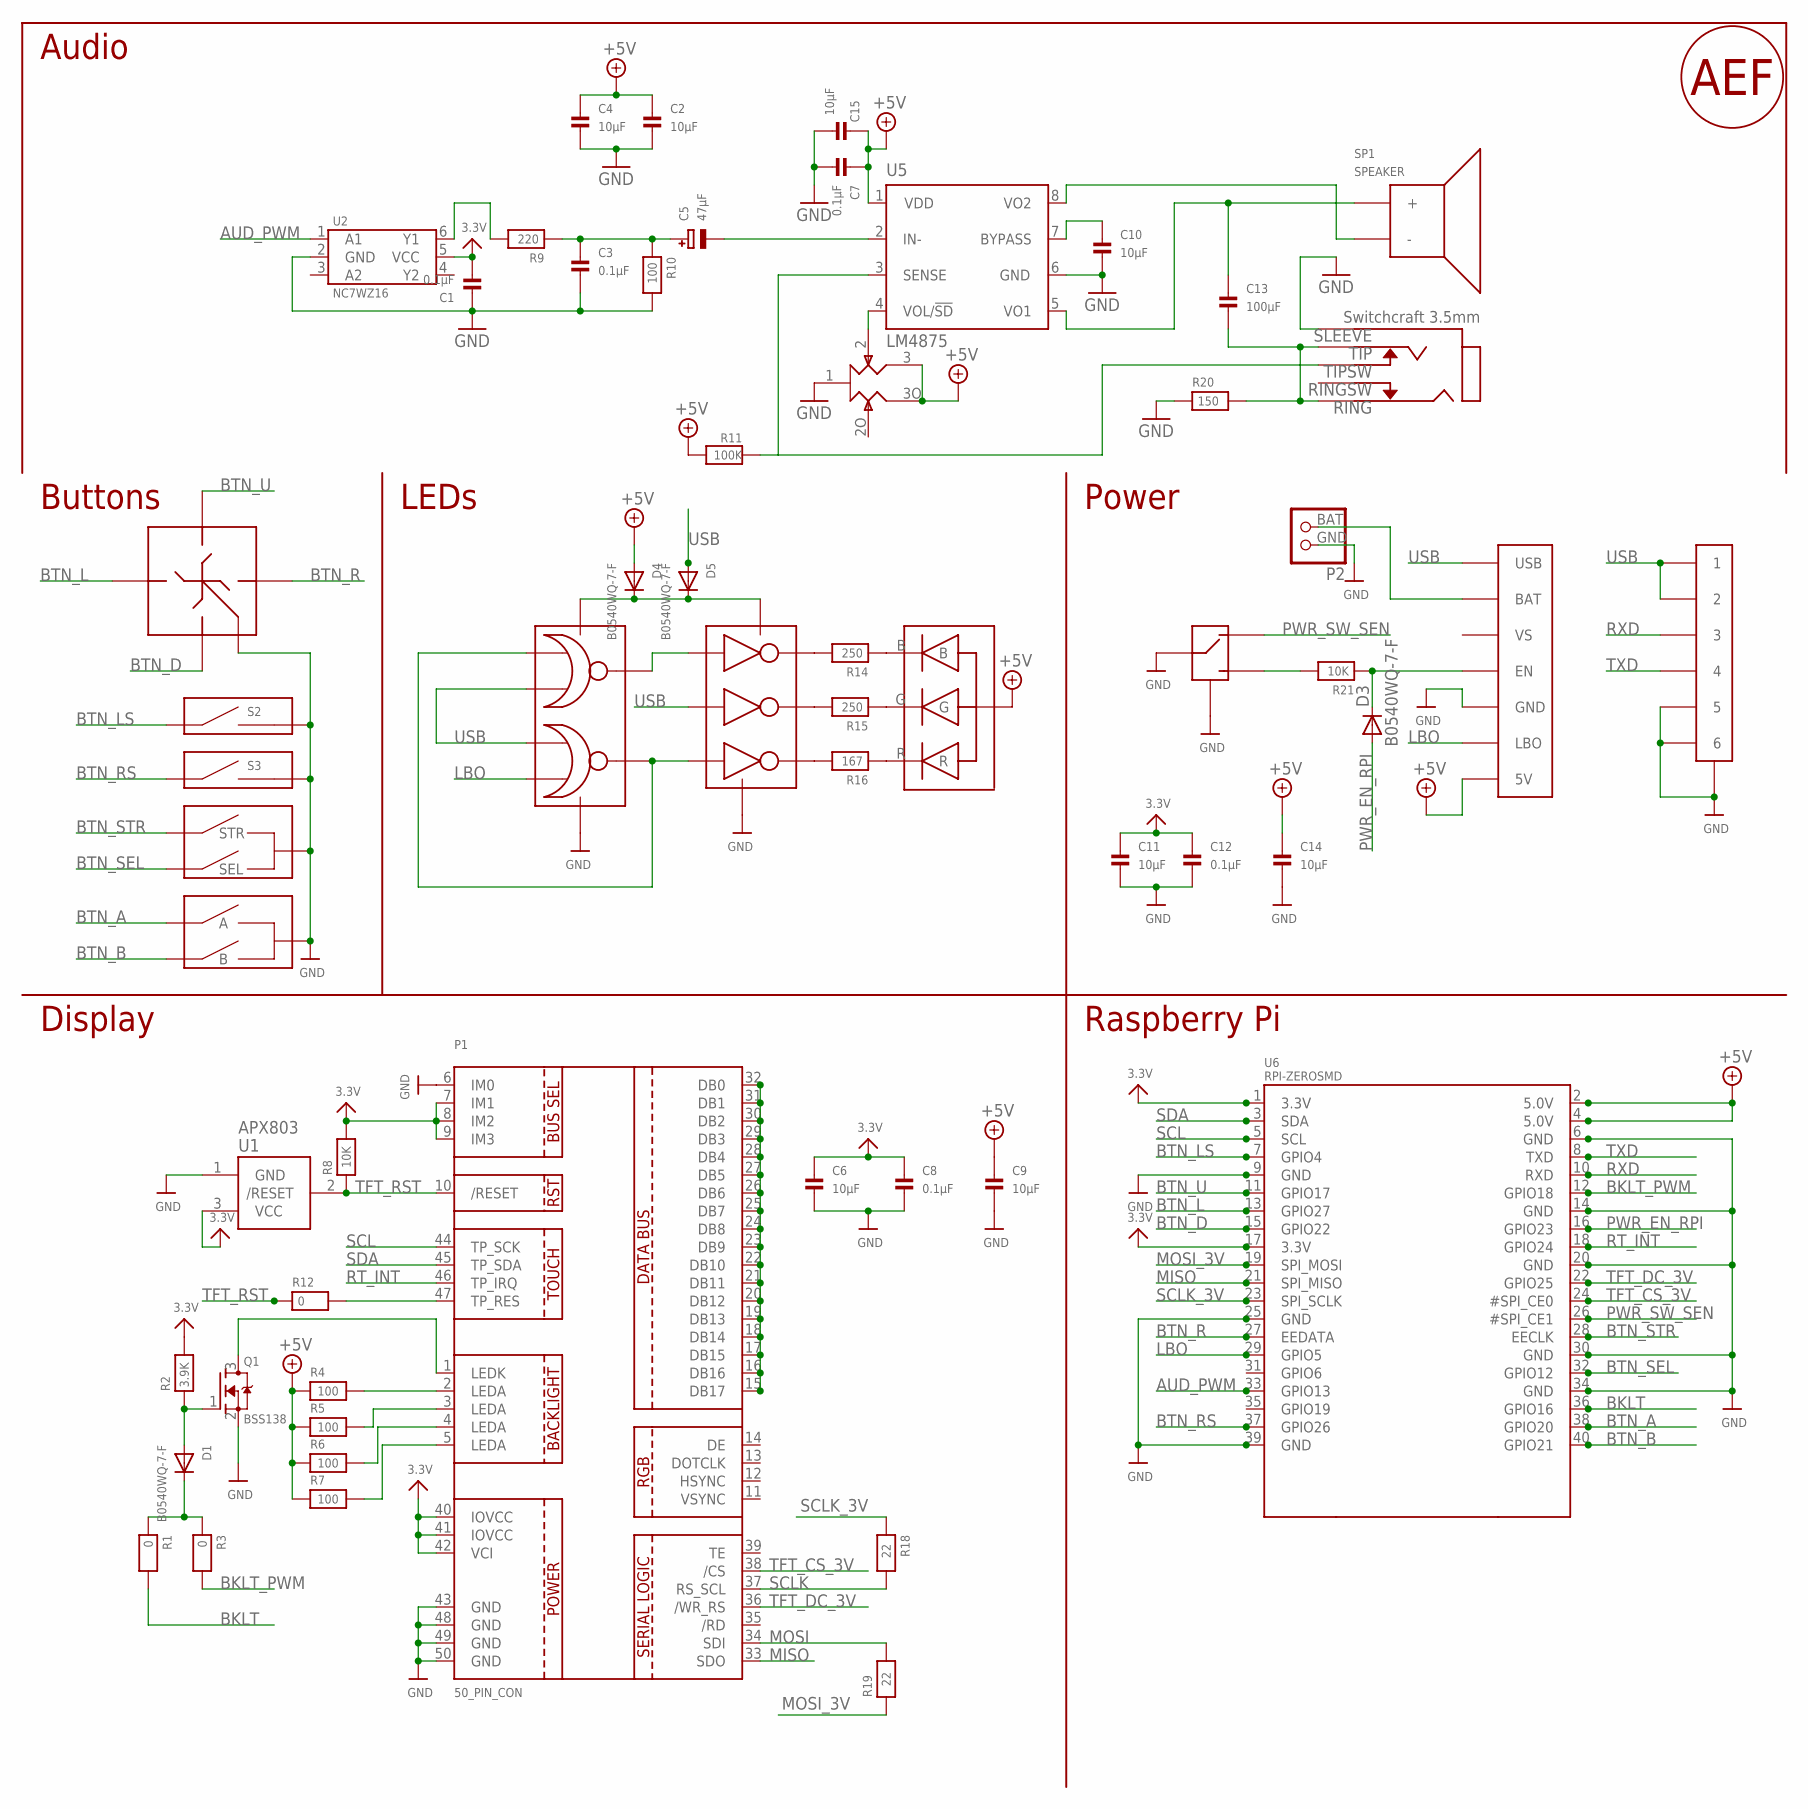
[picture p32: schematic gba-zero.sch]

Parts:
C1, C3, C7, C8, C12: 0.1μF; 0603
C2, C4, C6, C9, C10, C11, C14, C15: 10μF; 0603
C5: 47μF; EIA6032-28/C-R
C13: 100μF; 1206
D1, D3, D4, D5: B0540WQ-7-F; SOD-123
D2: LTST-C19HE1WT; WL-SBCW-0606
J1: SWTCHCRFT_3.5JACK5-JACK-SMD; 4-JACK-SMD
P1: 50_PIN_CON; FPC-50-CON
P2: JST_2PIN; JSTPH2
P3: LINK_CONNECTOR
Q1: BSS138; SOT23-WIDE
R1, R3, R12: 0; 0603
R2: 3.9K; 0603
R4, R5, R6, R7, R10: 100; 0603
R8, R21: 10K; 0603
R9: 220; 0603
R11: 100K; 0603
R14, R15: 250; 0603
R16: 167; 0603
R17: 10K; RK10J12E0A0A
R18, R19: 22; 0603
R20: 150; 0603
S1: D-PAD
S2, S3: SHOULDER_BUTTON
S4: START_SELECT_BUTTON
S5: AB_BUTTON
S6: PWR_SWITCH; PWR-SWITCH
SP1: SPEAKER
U1: APX803; SOT23
U2: NC7WZ16; SC-70-6
U3: 74LVC2G02; TSSOP-8
U4: 74LVC3G04; TSSOP-8
U5: LM4875; SO-8
U6: RPI-ZEROSMD; RPI-SMD
U7: POWERBOOST-1000C
U$1: SIGNATURE

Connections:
3.3V: C1.2, C6.1, C8.1, C11.1, C12.1, P1.7 (IM1), P1.8 (IM2), P1.9 (IM3), P1.40 (IOVCC), P1.41 (IOVCC), P1.42 (VCI), R2.2, R8.2, U1.3 (VCC), U2.5 (VCC), U6.1 (3.3V), U6.17 (3.3V)
+5V: C2.1, C4.1, C7.1, C9.1, C14.1, C15.1, D2.VCC, D4.A, R4.1, R5.1, R6.1, R7.1, R11.2, R17.3, R17.3O, U5.1 (VDD), U6.2 (5.0V), U6.4 (5.0V), U7.5V
AUD_PWM: U2.1 (A1), U6.33 (GPIO13)
BAT: P2.BAT (2), U7.BAT
BKLT: R1.2, U6.36 (GPIO16)
BKLT_PWM: R3.2, U6.12 (GPIO18)
BTN_A: S5.A@1 (A), S5.A@2 (A), U6.38 (GPIO20)
BTN_B: S5.B@1 (B), S5.B@2 (B), U6.40 (GPIO21)
BTN_D: S1.DOWN, U6.15 (GPIO22)
BTN_L: S1.LEFT, U6.13 (GPIO27)
BTN_LS: S2.SW (1), U6.7 (GPIO4)
BTN_R: S1.RIGHT, U6.27 (EEDATA)
BTN_RS: S3.SW (1), U6.37 (GPIO26)
BTN_SEL: S4.SEL, U6.32 (GPIO12)
BTN_STR: S4.STR, U6.28 (EECLK)
BTN_U: S1.UP, U6.11 (GPIO17)
BYPASS: C10.1, U5.7 (BYPASS)
GND: C1.1, C2.2, C3.2, C4.2, C6.2, C7.2, C8.2, C9.2, C10.2, C11.2, C12.2, C14.2, C15.2, J1.1, P1.6 (IM0), P1.43 (GND), P1.48 (GND), P1.49 (GND), P1.50 (GND), P2.GND (1), P3.5, P3.6, P3.GND@1 (GND), P3.GND@2 (GND), Q1.2 (S), R10.2, R17.1, R20.1, S1.GND@1 (GND), S1.GND@2 (GND), S1.GND@3 (GND), S1.GND@4 (GND), S2.GND@1 (2), S2.GND@2 (2), S2.GND@3 (2), S3.GND@1 (2), S3.GND@2 (2), S3.GND@3 (2), S4.GND@1 (GND), S4.GND@2 (GND), S4.GND@3 (GND), S4.GND@4 (GND), S5.GND@1 (GND), S5.GND@2 (GND), S5.GND@3 (GND), S5.GND@4 (GND), S6.C@1 (C), S6.C@2 (C), S6.GND@1 (GND), S6.GND@2 (GND), U1.1 (GND), U2.2 (GND), U3.4 (GND), U4.4 (GND), U5.6 (GND), U6.6 (GND), U6.9 (GND), U6.14 (GND), U6.20 (GND), U6.25 (GND), U6.30 (GND), U6.34 (GND), U6.39 (GND), U7.GND@1 (GND), U7.GND@2 (GND)
LBO: U3.6 (2B), U6.29 (GPIO5), U7.LBO
MISO: P1.33 (SDO), U6.21 (SPI_MISO)
MOSI: P1.34 (SDI), R19.2
MOSI_3V: R19.1, U6.19 (SPI_MOSI)
unnamed: P1.1 (LEDK), Q1.3 (D)
unnamed: P1.5 (LEDA), R7.2
unnamed: P1.4 (LEDA), R6.2
unnamed: P1.3 (LEDA), R5.2
unnamed: R16.2, U4.2 (3Y)
unnamed: D1.C, R1.1, R3.1
unnamed: D1.A, Q1.1 (G), R2.1
unnamed: D2.R, R16.1
unnamed: P1.15 (DB17), P1.16 (DB16), P1.17 (DB15), P1.18 (DB14), P1.19 (DB13), P1.20 (DB12), P1.21 (DB11), P1.22 (DB10), P1.23 (DB9), P1.24 (DB8), P1.25 (DB7), P1.26 (DB6), P1.27 (DB5), P1.28 (DB4), P1.29 (DB3), P1.30 (DB2), P1.31 (DB1), P1.32 (DB0)
unnamed: P1.2 (LEDA), R4.2
unnamed: R15.2, U4.5 (2Y)
unnamed: D2.G, R15.1
unnamed: R14.2, U4.7 (1Y)
unnamed: D2.B, R14.1
unnamed: U3.7 (1Y), U4.1 (1A)
unnamed: U3.1 (1A), U3.3 (2Y), U4.6 (3A)
unnamed: R21.2, S6.R
unnamed: D3.C, R21.1, U7.EN
unnamed: D4.C, D5.C, U3.8 (VCC), U4.8 (VCC)
unnamed: R9.2, U2.6 (Y1)
unnamed: C3.1, C5.+, R9.1, R10.1
unnamed: P1.47 (TP_RES), R12.2
unnamed: C5.-, U5.2 (IN-)
PWR_EN_RPI: D3.A, U6.16 (GPIO23)
PWR_SW_SEN: S6.L, U6.26 (#SPI_CE1)
RING: C13.2, J1.2, J1.3, R20.2
RT_INT: P1.46 (TP_IRQ), U6.18 (GPIO24)
RXD: P3.3, U6.10 (RXD)
SCL: P1.44 (TP_SCK), U6.5 (SCL)
SCLK: P1.37 (RS_SCL), R18.2
SCLK_3V: R18.1, U6.23 (SPI_SCLK)
SDA: P1.45 (TP_SDA), U6.3 (SDA)
SENSE: J1.5, R11.1, U5.3 (SENSE)
TFT_CS_3V: P1.38 (/CS), U6.24 (#SPI_CE0)
TFT_DC_3V: P1.36 (/WR_RS), U6.22 (GPIO25)
TFT_RST: P1.10 (/RESET), R8.1, R12.1, U1.2 (/RESET)
TXD: P3.4, U6.8 (TXD)
USB: D5.A, P3.1, P3.2, U3.2 (1B), U3.5 (2A), U4.3 (2A), U7.USB
VO1: C13.1, SP1.1 (+), U5.5 (VO1)
VO2: SP1.2 (-), U5.8 (VO2)
VOL/SD: R17.2, U5.4 (VOL/!SD)

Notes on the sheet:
Buttons
LEDs
Power
Raspberry Pi
Display
Audio

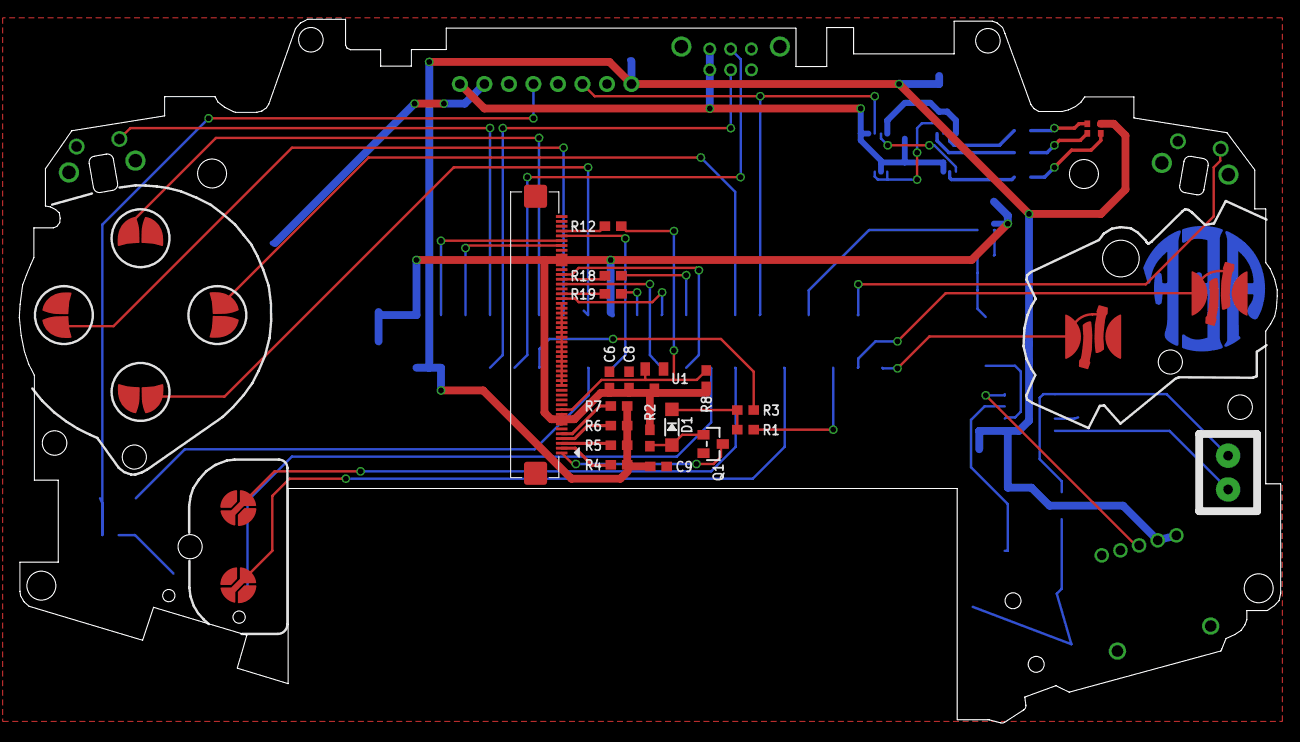
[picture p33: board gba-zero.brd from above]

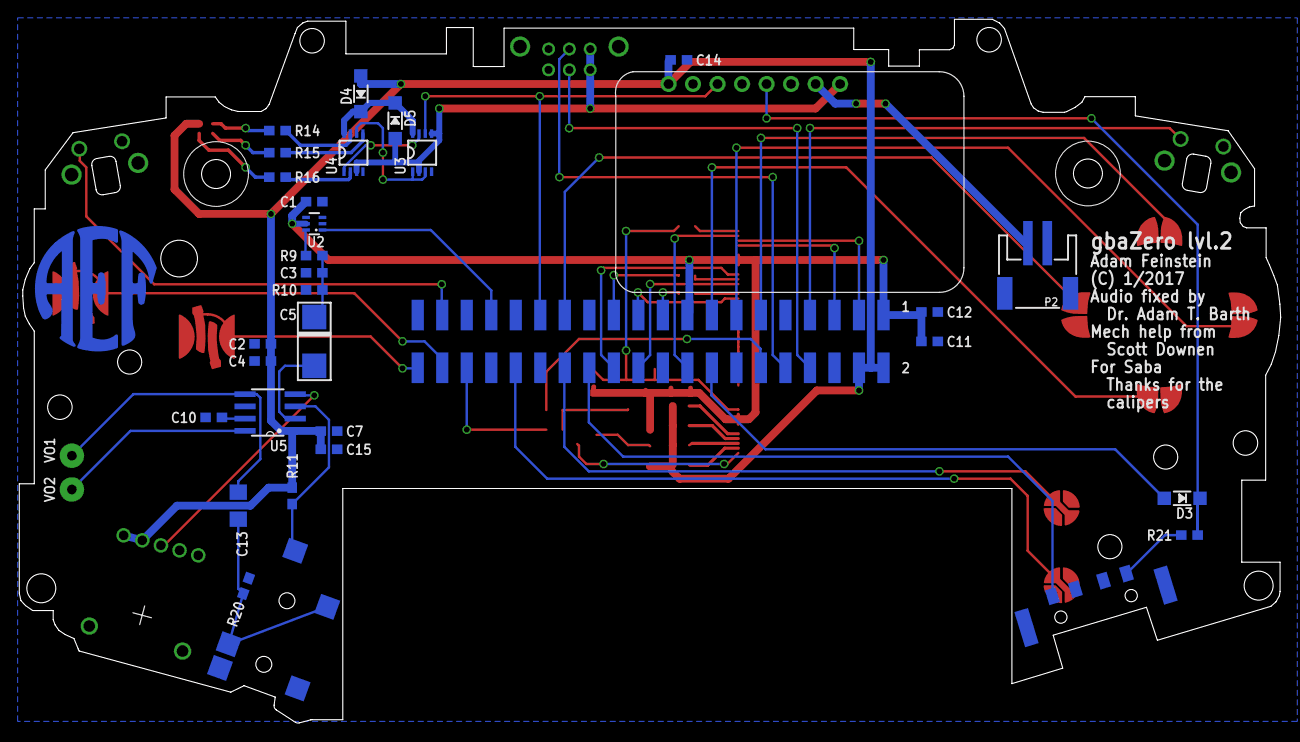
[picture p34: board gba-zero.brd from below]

Board: 2 copper layers, 130.7 x 72.9 mm, 60 parts (34 on the bottom side), 63 nets.

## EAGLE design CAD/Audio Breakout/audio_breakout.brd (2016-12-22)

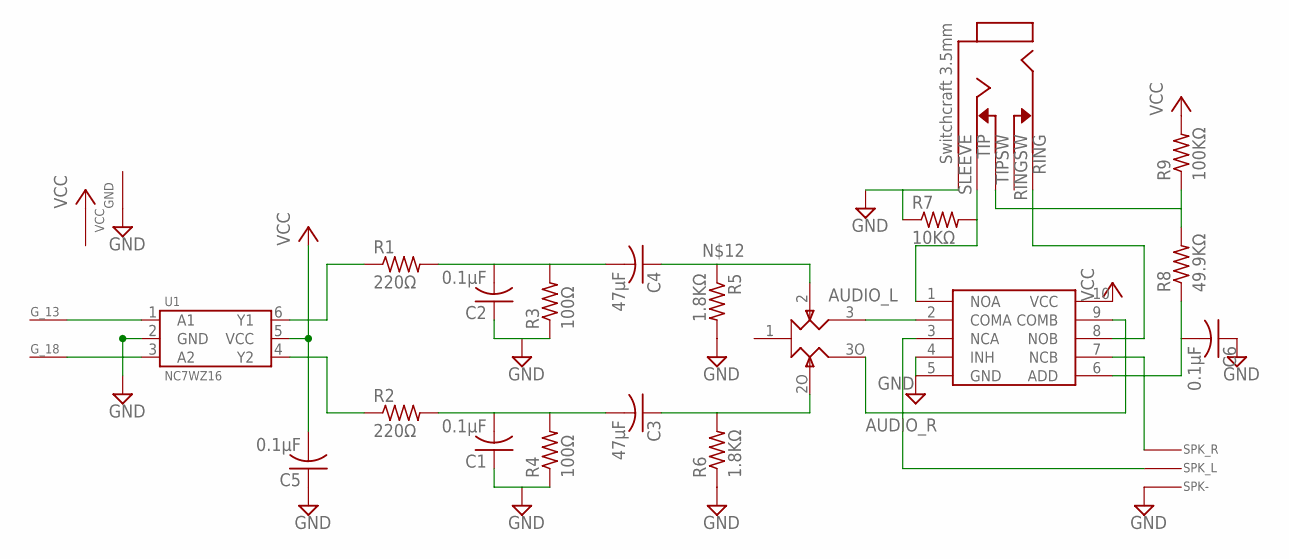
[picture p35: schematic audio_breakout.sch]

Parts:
C1, C2, C5, C6: 0.1μF; C0603
C3, C4: 47μF; C0603
GND: THROUGH-HOLE
G_13, G_18: THROUGH-HOLE
R1, R2: 220Ω; R0603
R3, R4: 100Ω; R0603
R5, R6: 1.8KΩ; R0603
R7: 10KΩ; R0603
R8: 49.9KΩ; R0603
R9: 100KΩ; R0603
SPK-: THROUGH-HOLE
SPK_L: THROUGH-HOLE
SPK_R: THROUGH-HOLE
U1: NC7WZ16; SC-70-6
U2: MAX4525L; UMAX10
U$2: SWTCHCRFT_3.5JACK5-JACK-SMD; 4-JACK-SMD
U$3: 10K; RK10J12E0A0A
VCC: THROUGH-HOLE

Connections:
AUDIO_L: U2.2 (COMA), U$3.3
AUDIO_R: U2.9 (COMB), U$3.3O
GND: C1.1, C2.1, C5.1, C6.1, GND.P$1, R3.1, R4.1, R5.2, R6.1, R7.1, SPK-.P$1, U1.2 (GND), U2.4 (INH), U2.5 (GND), U$2.1
unnamed: R1.1, U1.6 (Y1)
unnamed: R2.1, U1.4 (Y2)
unnamed: C1.2, C3.2, R2.2, R4.2
unnamed: C2.2, C4.2, R1.2, R3.2
unnamed: R8.2, R9.1, U$2.5
unnamed: C6.2, R8.1, U2.6 (ADD)
unnamed: G_18.P$1, U1.3 (A2)
unnamed: G_13.P$1, U1.1 (A1)
unnamed: SPK_R.P$1, U2.7 (NCB)
unnamed: R7.2, U2.1 (NOA), U$2.3
unnamed: U2.8 (NOB), U$2.2
unnamed: C4.1, R5.1, U$3.2
unnamed: SPK_L.P$1, U2.3 (NCA)
unnamed: C3.1, R6.2, U$3.2O
VCC: C5.2, R9.2, U1.5 (VCC), U2.10 (VCC), VCC.P$1

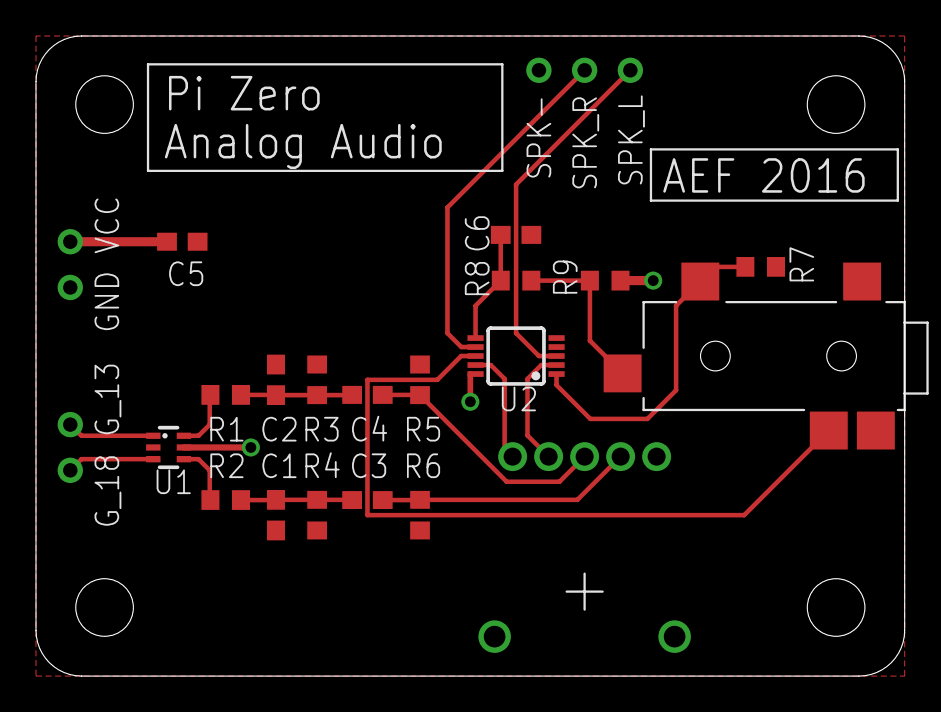
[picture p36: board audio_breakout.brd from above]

Board: 2 copper layers, 48.3 x 35.6 mm, 26 parts (0 on the bottom side), 18 nets.

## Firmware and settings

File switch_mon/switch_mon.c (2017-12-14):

#include <stdlib.h>
#include <wiringPi.h>
#include <unistd.h>
#include <time.h>
#include <sys/time.h>
#include <stdint.h>

/* The power sense pin is physical pin 26, wiringPi pin 11
 */
#define PWR_SENSE_PIN 11

typedef enum
{
  TURNED_ON,
  PROCESS_KILLED,
} shutdownState_t;

int main (void)
{
  shutdownState_t shutdownState = TURNED_ON;
  /* Assume the pin is low at the start */
  uint8_t pinHistory = 0x00;

  /* Initialize the wiring library */
  wiringPiSetup();

  /* This should already be initialized by /etc/rc.local, but just
   * in case, set the power sense pin as an input with pullup
   */
  pinMode(PWR_SENSE_PIN, INPUT);
  pullUpDnControl (PWR_SENSE_PIN, PUD_UP);

  //system("echo starting_shutdown >> /home/pi/shutdown_log.txt");

  /* To not hog the CPU */
  while (1)
  {
    /* Read the pin once a second */
    pinHistory <<= 1;
    if(HIGH == digitalRead(PWR_SENSE_PIN))
    {
      pinHistory |= 1;
    }

    switch(shutdownState)
    {
      case TURNED_ON:
        {
          /* If the pin has been high for four consecutive seconds */
          if((pinHistory & 0x0F) == 0x0F)
          {
            /* Kill emulation station, but leave the GPIO on */
            //system("echo killing_progs >> /home/pi/shutdown_log.txt");
            system("killall emulationstation");
            system("killall retroarch");
            shutdownState = PROCESS_KILLED;
          }
          break;
        }
      case PROCESS_KILLED:
        {
          /* If the pin has been high for four consecutive seconds
           * then it's safe to turn off the GPIO and shut down
           */
          if((pinHistory & 0x0F) == 0x00)
          {
            //system("echo shutting_down >> /home/pi/shutdown_log.txt");
            /* Turn the GPIO off */
            digitalWrite(4, 0);
            /* Start the shutdown process */
            system("shutdown -P now");
            return 0;
          }
          break;
        }
    }

    /* Don't hog the CPU */
    sleep(1);
  }

  return 0 ;
}

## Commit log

2016-11-24 Did CAD work for D-Pad, Start & Select buttons
2016-11-25 Added link connector & shoulder button parts.
    TODO: verify electrical connections
2016-11-26 Parts & Schematic almost done, except AB buttons
    [gba-zero.brd, gba-zero.sch]
2016-11-26 Added AB_BUTTON part to library & schematic
    [gba-zero.brd, gba-zero.sch]
2016-11-28 Added audio to schematic
    [gba-zero.brd, gba-zero.sch]
2016-11-28 Lots of schematic cleanup
    [gba-zero.brd, gba-zero.sch]
2016-11-28 Added JST battery connector
    [gba-zero.brd, gba-zero.sch]
2016-12-01 Added new parts for SMD RPI, just the 510 pin FPC connector Sorted parts in the layout
    [gba-zero.brd, gba-zero.sch]
2016-12-01 Added Ryzee's parts for placement
    [gba-zero.brd, gba-zero.sch]
2016-12-02 Started the layout. Tweaking parts as necessary
    [gba-zero.brd, gba-zero.sch]
2016-12-03 Routed right side of the board
    [gba-zero.brd, gba-zero.sch]
2016-12-04 More Routing
    [gba-zero.brd, gba-zero.sch]
2016-12-04 Display is routed, some other stuff was unrouted
    [gba-zero.brd, gba-zero.sch]
2016-12-05 Fully Routed
    [gba-zero.brd, gba-zero.sch]
2016-12-05 Cleared all DRC errors
    [gba-zero.brd, gba-zero.sch]
2016-12-05 Final board tweaks Added DRU file
    [gba-zero.brd, gba-zero.sch]
2016-12-05 Switched DFRobot to SeeedStudio files
    [gba-zero.brd]
2016-12-05 Added value layers to the silkscreen
2016-12-05 Renumbered parts
    [gba-zero.brd, gba-zero.sch]
2016-12-05 Fixed u vs. μ Removed jack outline from bPlace Fixed the date on the silk
    [gba-zero.brd, gba-zero.sch]
2016-12-05 Added Gerber files
    [gba-zero.GBL, gba-zero.GBO, gba-zero.GBP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]
2016-12-06 Improved soldermask around d-pad and A&B buttons
    [gba-zero.brd, gba-zero.sch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]
2016-12-22 Added Audio Breakout files
    [audio_breakout.brd, audio_breakout.sch]
2016-12-22 Added BOM, odds and ends images
    [bom.ods]
2016-12-26 Rerouted display control lines Added missing connection between pins 10 & 47 on the display connector
    [gba-zero.brd, gba-zero.sch]
2016-12-26 Shifted display hardware, added more space in the battery area
    [gba-zero.brd]
2016-12-26 Added diodes to power LED logic by USB & regulated 5V Cleaned up layout
    [gba-zero.brd, gba-zero.sch]
2016-12-26 Added LBO to a GPIO5
    [gba-zero.brd, gba-zero.sch]
2016-12-26 Moved RPi Zero up a little
    [gba-zero.brd]
2016-12-26 Updated APX803 to the right voltage on the BOM
    [bom.ods]
2016-12-26 Replaced 0805s with 0603s Fattened power traces
    [gba-zero.brd, gba-zero.sch]
2016-12-26 Fixed TSSOP-8 package
    [gba-zero.brd, gba-zero.sch]
2016-12-26 Swapped VCC & GND for the volume dial
    [gba-zero.brd, gba-zero.sch]
2016-12-26 Cleaned up the silkscreen
    [gba-zero.brd, gba-zero.sch]
2016-12-27 Fixed drill sizes Smoothed out top edge
    [gba-zero.brd, gba-zero.sch]
2016-12-27 Switched shoulder button footprint to one I can buy on digikey
    [gba-zero.brd, gba-zero.sch]
2016-12-28 Updated BOM
    [bom.ods]
2016-12-28 Updated BOM with quantity and part numbers
    [bom.ods]
2016-12-29 Tweaked bypass capacitor values (C7, C10, C15) Removed unnecessary HP Sense resistor (R13) Removed pulldown resistor before amp (R12)
    [gba-zero.brd, gba-zero.sch]
2016-12-29 Updated silkscreen Added 0 ohm to display connector for theoretical resistive compatibility Updated bom.ods
    [bom.ods, gba-zero.brd, gba-zero.sch]
2016-12-30 Added signature
    [gba-zero.brd, gba-zero.sch]
2016-12-30 Cleaned up traces because OCD
    [gba-zero.brd]
2016-12-30 Updated Gerbers
    [gba-zero.GBL, gba-zero.GBO, gba-zero.GBP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]
2016-12-31 Updated schematic, board, Gerbers, and BOM to use Seeed Studio PCBA parts where possible Updated CAM job to not silk t/bValue layers Shifted a drill hole just a little
    [bom.ods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]
2016-12-31 Added seeed-bom.csv
    [seeed-bom.csv]
2016-12-31 Removed battery connector from seeed-bom.csv
    [bom.ods, seeed-bom.csv]
2016-12-31 Updated silkscreen & gerbers
    [gba-zero.brd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]
2017-01-02 Added images from the assembly process
2017-01-03 Added scaled PCB image
2017-01-04 Updated final Assembly/28 - Final Assembly.jpg
2017-01-05 Expanded battery area in PCB Removed R1, R3 from seeed-bom.csv, since they are DNP Regenerated gerbers
    [gba-zero.GBL, gba-zero.GBO, gba-zero.GBP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]
2017-01-05 Fixed text orientation for speaker through holes
    [gba-zero.brd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]
2017-01-05 Added gerber zips
2017-12-14 Added switch_mon program
2018-01-13 Updated README.md with v2 PCB info

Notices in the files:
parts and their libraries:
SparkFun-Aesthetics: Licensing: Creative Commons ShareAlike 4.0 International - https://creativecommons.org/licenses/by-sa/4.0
